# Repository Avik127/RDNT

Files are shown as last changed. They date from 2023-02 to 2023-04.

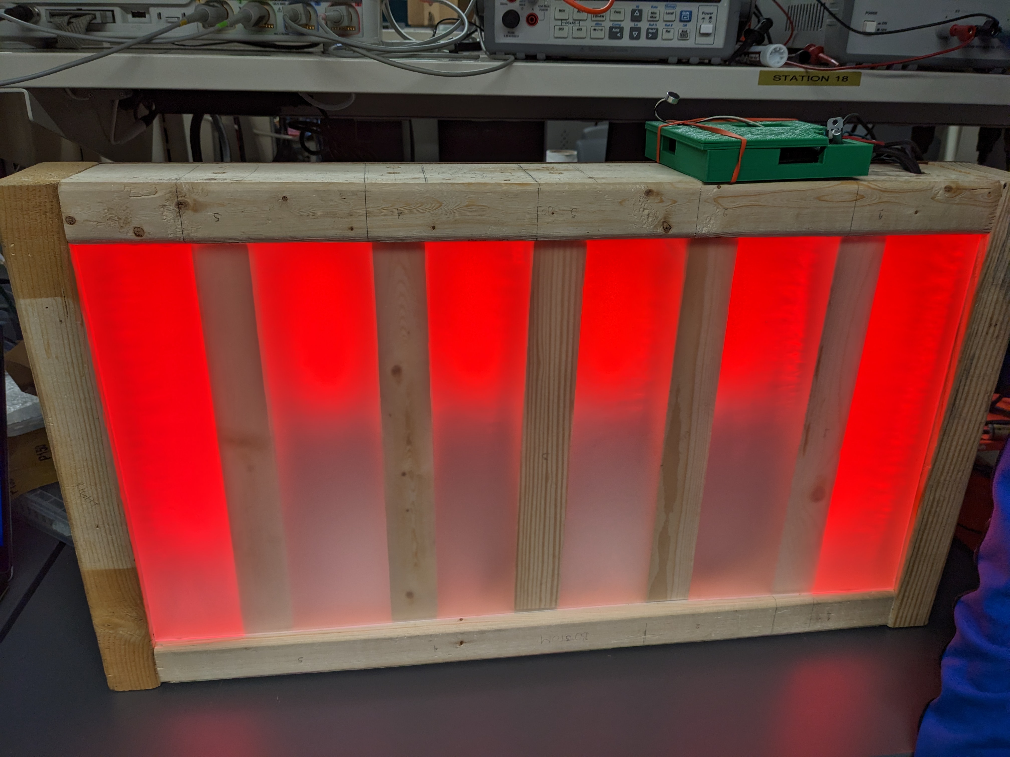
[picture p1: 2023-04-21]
website/Team/progress/progress2pics/final_construction_2.jpg

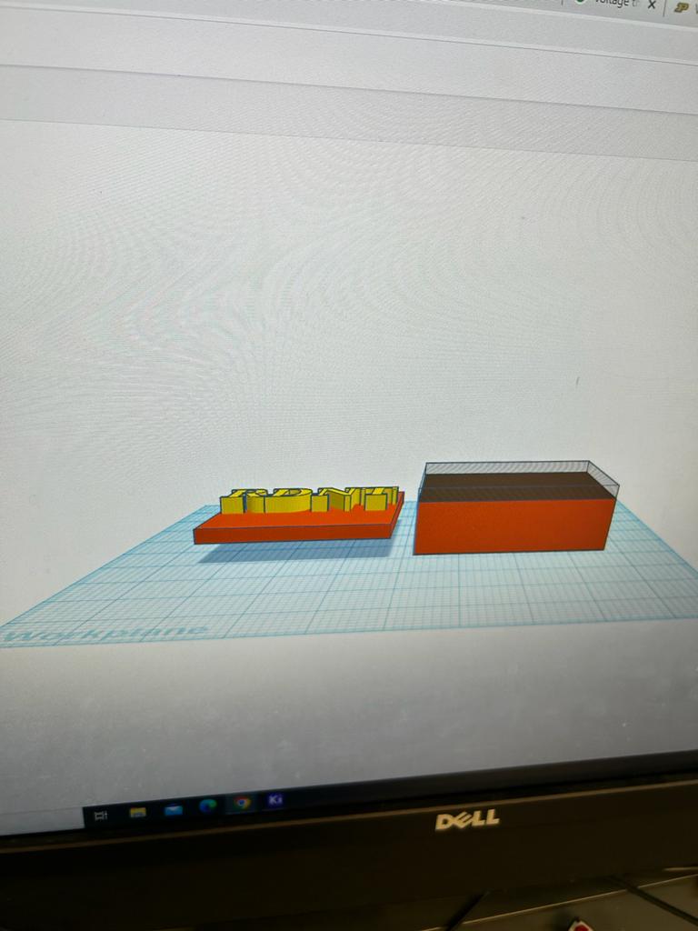
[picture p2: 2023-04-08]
website/Team/progress/resources4/design02.jpeg

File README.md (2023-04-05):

# RDNT

RDNT is a project that takes an input audio source and runs signal processing algorithms to drive wired LED strips to create a synchronized audio-visual experience. These audio sources are an onboard analog microphone, an AUX-in port, and a Bluetooth signal from our associated Android app. The user will be able to toggle through the 3 modes, with the microphone being the default, by pressing an external button. This mode toggling will be achieved through a multiplexxed circuit that selects the current mode.
The signal processing algorithms that will be used are the FFT algorithm and a 1-D Gaussian filter. The Gaussian filter reduces noise on the input sample and the FFT algorithm uses this noise reduced signal to isolate frequencies. The LED strips will be driven by a message sender that accepts the output of FFT to create patterns on the wired LED strips.
To create patterns we will send PWM signals to the data pin of the LED strips, these patterns and their associated color ranges can be selected by the user using the associated Android app. The microcontroller will read input samples and compute signal processing algorithms to drive the message sender. The LED strips will be powered by a wall adapter from 120V AC to 5V DC. A switching regulator circuit will drop the 5V DC to 3.3V DC for our microcontroller. For demonstration purposes, we will construct an acrylic display.

See our website for more information: https://engineering.purdue.edu/477grp18/

Current Stage: Soldering components onto our PCB, working on final software, and creating device packaging

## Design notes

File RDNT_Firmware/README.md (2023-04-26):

# RDNT_Firmware

## ESP32.zip

This is the final code shipped for the project.

## PCB Verification Files

These files are used for testing the project as we solder on components. They are described below:

### TestMCU_CaseLED.c
This program requires FastLED library and runs in the Arduino framework. It blinks the LEDs white and black.

### TestMCU_CaseLEDNoLibraries.c
This program requies no libraries and implements the same functions as above by manually controlling the PWM signals. This program uses Espressif-IDF framework and is closer to the final implementation.

### TestMCU_ModeButton.c
This program is used to test that the mode button has been implemented correctly. It is lacking state reflection on the case LED, that will be implemented in the next file.

## Prototyping Tools

These are main.c or main.cpp files that have were used in early prototyping. Many of these files are lacking dependencies but these are clear from reading the files. None of these files are fit for release and exist here solely for archival purposes. Use at your own caution.

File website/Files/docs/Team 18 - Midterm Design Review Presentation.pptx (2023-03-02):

## ECE477 MIDTERM DESIGN REVIEW: TEAM #18

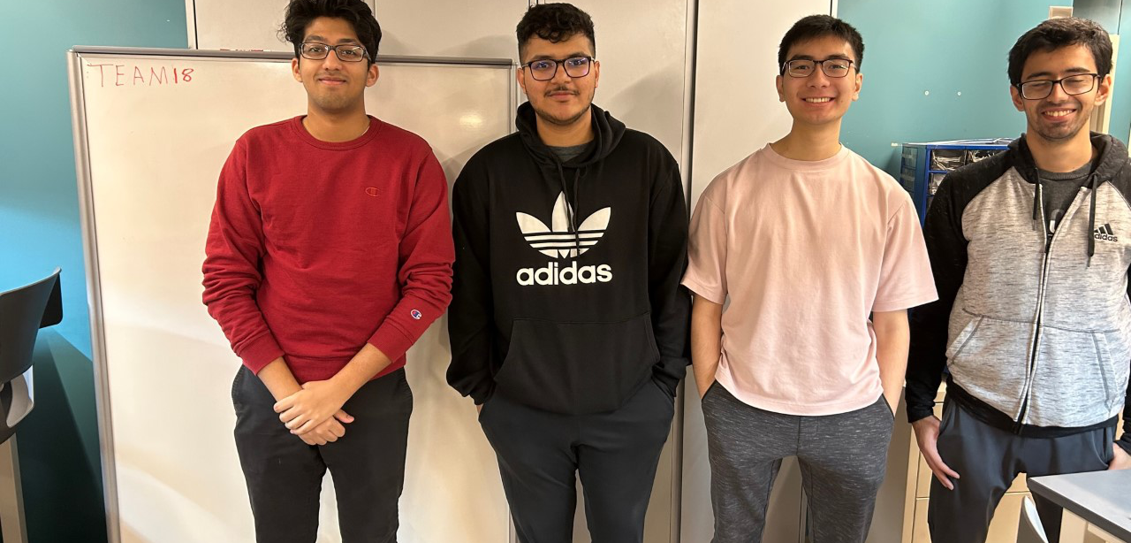
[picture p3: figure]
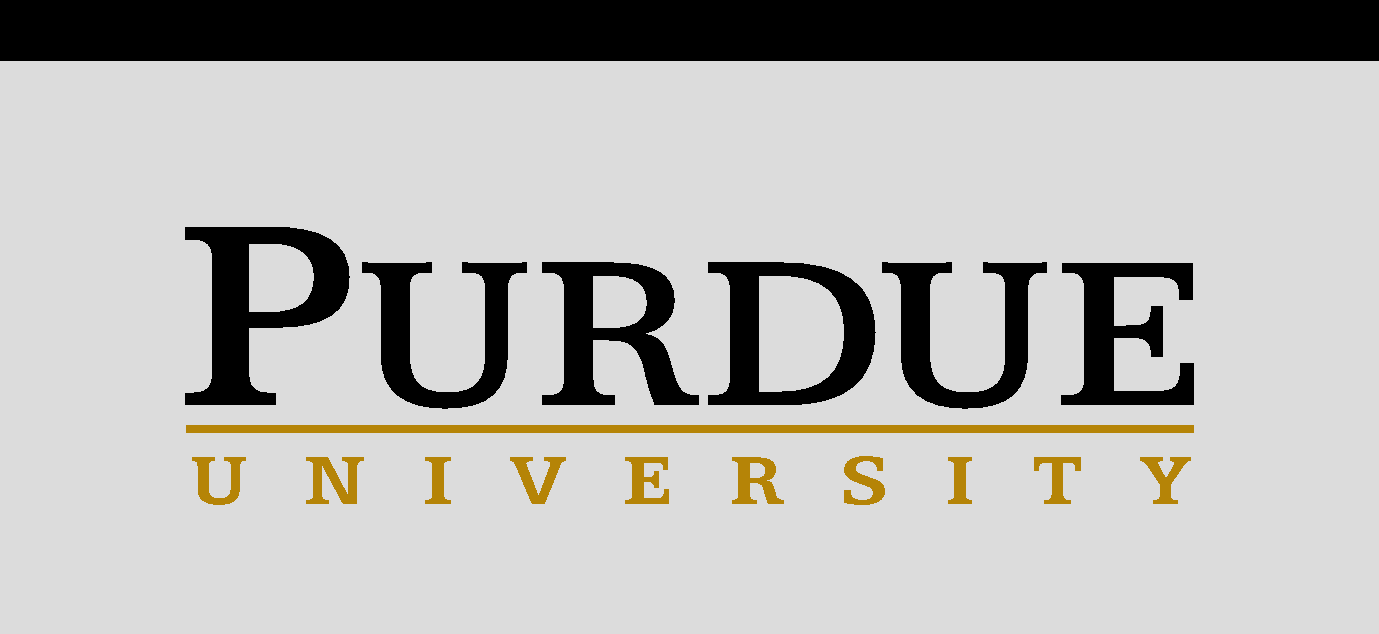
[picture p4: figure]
PU_sigtab.eps

## OUTLINE

- Project Overview
- PSSCs
- Block Diagram
- Major Components
- Prototyping Progress
- Electrical Schematic
- PCB Layout
- Software Development Status
- Packaging Design
- Project Timeline
- Questions

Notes: anu

## PROJECT OVERVIEW

Audio visualizer that lights up an LED display to correspond with input audio
- Real time analysis of input audio
- Easily configure patterns and colors through associated Android app
- Multiple audio input modes: Microphone, AUX, Bluetooth

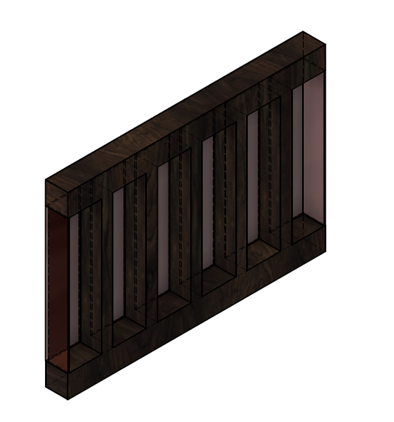
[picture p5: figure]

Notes: anu

## PSSCS

- PSSC #1 (Software): The ability to reduce noise on analog inputs through the use of a 1-D Gaussian Filtering algorithm.
- PSSC #2 (Software): The ability to control and configure multiple connected LED devices through a in-built bluetooth module that connects with Android app through UART.
- PSSC #3 (Hardware): The ability to amplify and filter analog input of the microphone using a sequence of operational amplifiers.
- PSSC #4 (Hardware): The ability for the user to toggle between input modes through multiplexed external controls. These modes will be Microphone (default), AUX-in, and Bluetooth audio.
- PSSC #5 (Hardware): The ability to drive multiple WS2812B LED strips with PWM signals and reactively display patterns in response to audio signals.
- Stretch Goal #1: The ability to isolate frequencies using the FFT algorithm.
- Stretch Goal #2: The ability to regulate power down from 5V DC to 3.3V DC with a switching regulator.

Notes: anu

## BLOCK DIAGRAM

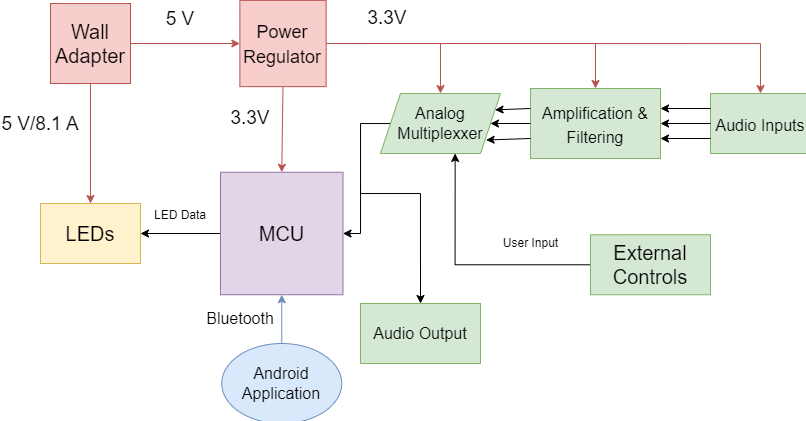
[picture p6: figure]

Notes: kahaan

## Component Selection: Synchronous Buck Converter

TPS56330

- 3.8V to 28V input voltage range
- 0.8V to 22V output voltage range
- 3-A continuous output current

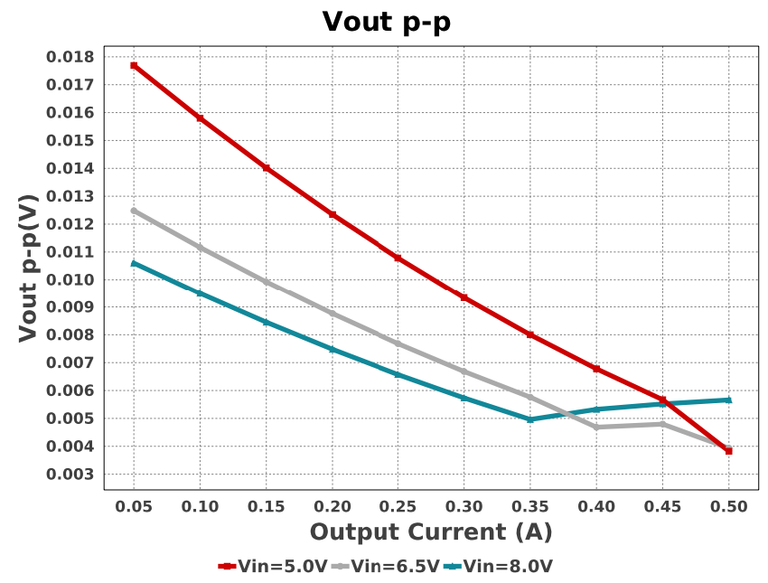
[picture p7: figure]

Voltage Input | 3.8V-28V
Voltage Output | 0.8V-22V
Current Output | 0A-3A

Recommended Characteristics

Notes: kahaan

## Component Selection: Microcontroller

ESP32-WROOM32

Selection Rationale:
- High Clock Speed: 80-240MHz
- Wi-Fi and Bluetooth capabilities
- Dual-Core CPU
- 520KB of RAM
- 4MB of Flash Memory
- 12-bit internal ADC peripheral
- Familiarity
- Cost effective

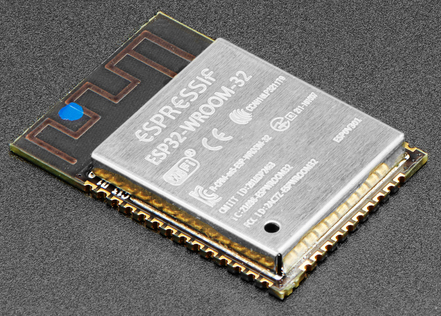
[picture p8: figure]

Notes: kahaan

## Component Selection: LEDs

WS2812B

Selection Rationale:
- 3-pin channels allow for individual addressability
  - Previous generation of LEDs (WS2811) only had separate channels for RGB
- Send data speed of 800 Kbps
- Scan frequency 400Hz

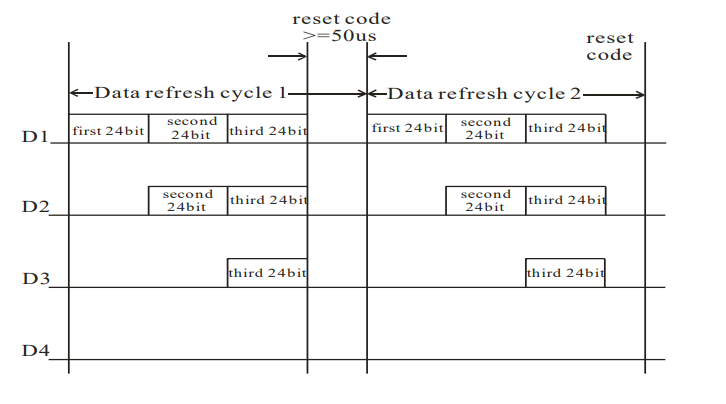
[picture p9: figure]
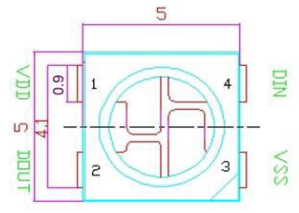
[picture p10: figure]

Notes: kahaan

## Prototyping Progress

Component | Status
Microphone Audio Filtering | 60%
Aux Input/Output | 80%
Power Circuit | 0%
Audio Multiplexer | 0%

The remaining progress in each of this component is primarily focused on software development:
- Audio filter through Gaussian Filtering algorithm
- AUX input output routing through Analog Multiplexer to AUX
- Audio input sampling, FFT, and visual pattern generation combined system

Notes: graeme

## Prototyping Progress

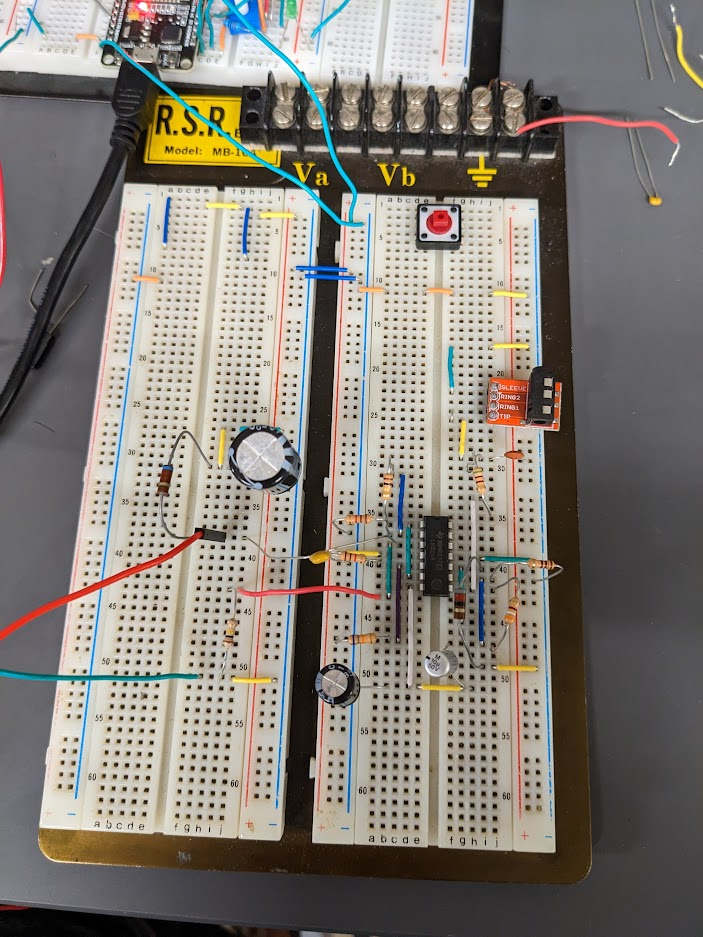
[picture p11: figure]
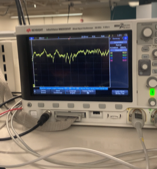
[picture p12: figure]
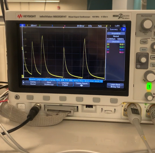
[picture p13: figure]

Microphone and AUX prototyping circuit, with oscilloscope readings

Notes: graeme

## ELECTRICAL SCHEMATIC

Full Schematic

## ELECTRICAL SCHEMATIC

Power

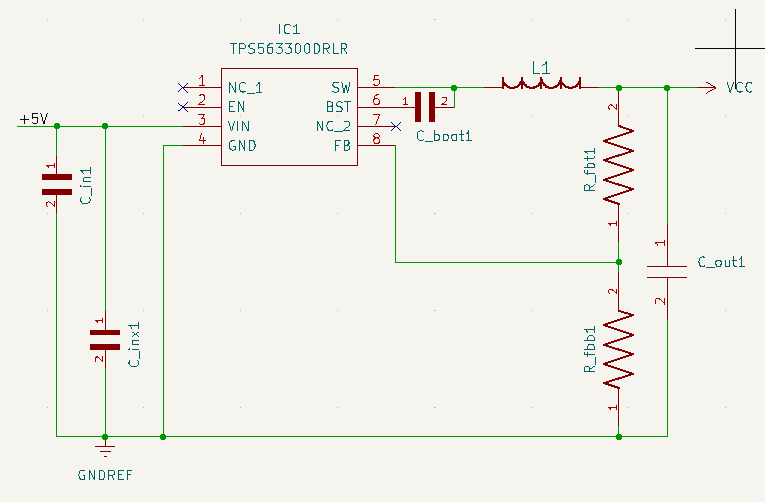
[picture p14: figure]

- Designed using the TI Power WEBENCH
- Input Voltage of 5V
- Supplies 3.3V @ 0.5A to the MCU

## ELECTRICAL SCHEMATIC

Mic Amplifier and Filtering

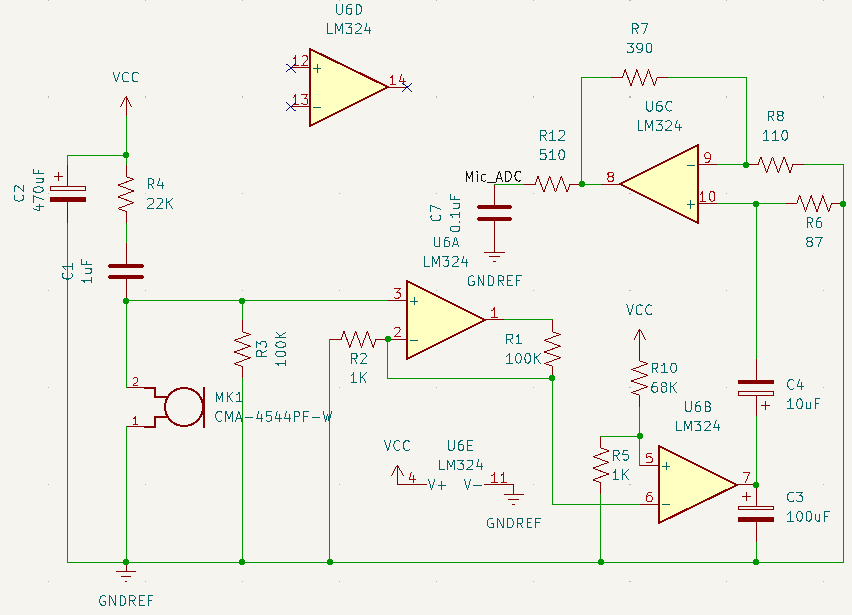
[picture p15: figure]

- Non-inverting op amp with a gain of 101x
  - Vout = Vin(1+(R1/R2))
- Low Pass Filter cutoff frequency @ ~3kHz
  - fc= 1/2πR12C7
- High Pass Filter cutoff frequency @ ~187Hz
  - fc= 1/2πR6C4

## ELECTRICAL SCHEMATIC

Analog Mux

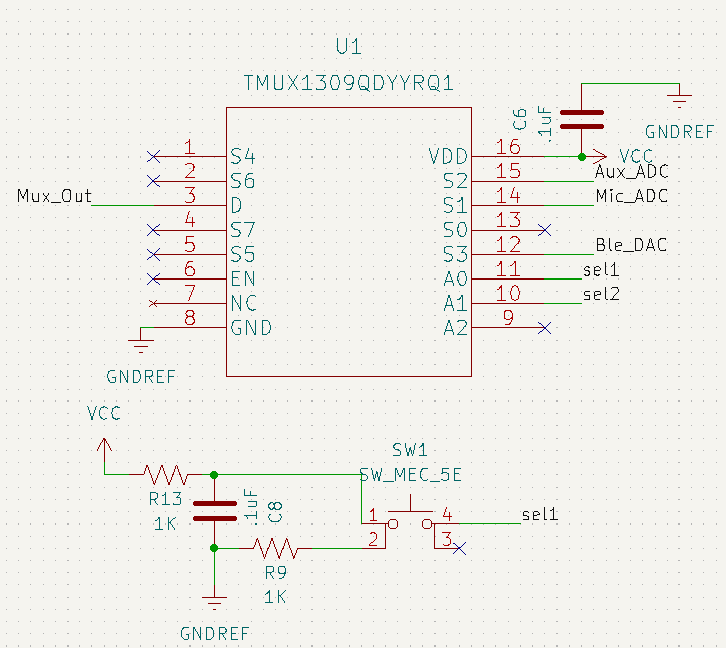
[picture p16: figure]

- Debouncing done on the mode-switching button
- Analog inputs are chosen through select lines controlled by MCU/push button

## ELECTRICAL SCHEMATIC

Aux Audio

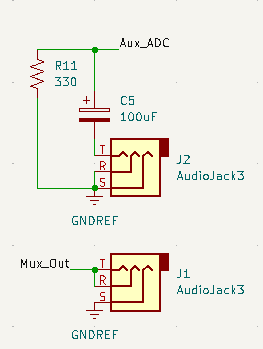
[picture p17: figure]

## ELECTRICAL SCHEMATIC

Microcontroller

## PCB LAYOUT

Full PCB

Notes: avik

## PCB LAYOUT

Power

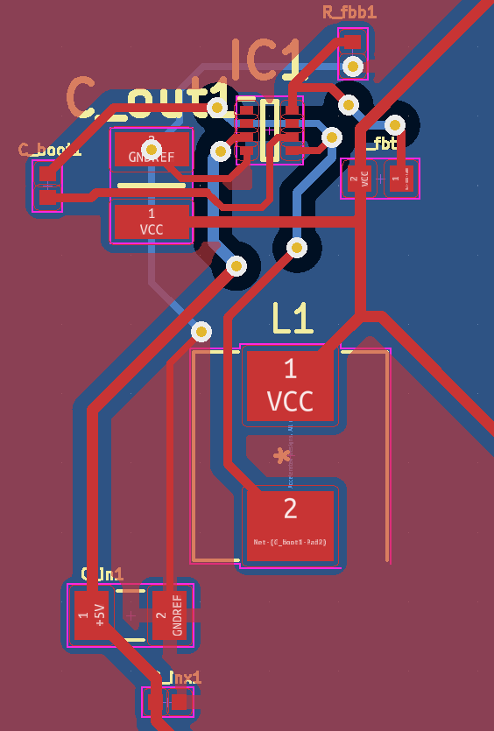
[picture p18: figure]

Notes: avik

## PCB LAYOUT

Microcontroller

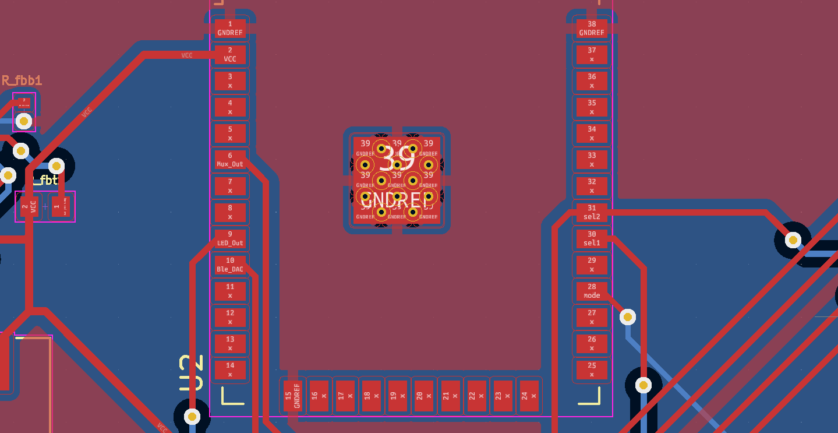
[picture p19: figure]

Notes: avik

## PCB LAYOUT

Aux Jacks

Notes: avik

## PCB LAYOUT

TMUX

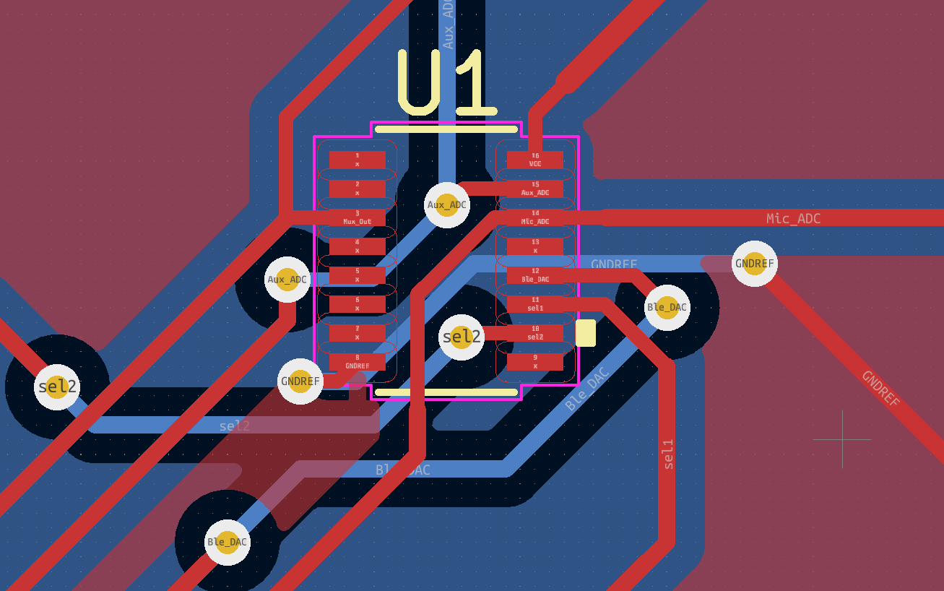
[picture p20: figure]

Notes: avik

## PCB LAYOUT

Mic

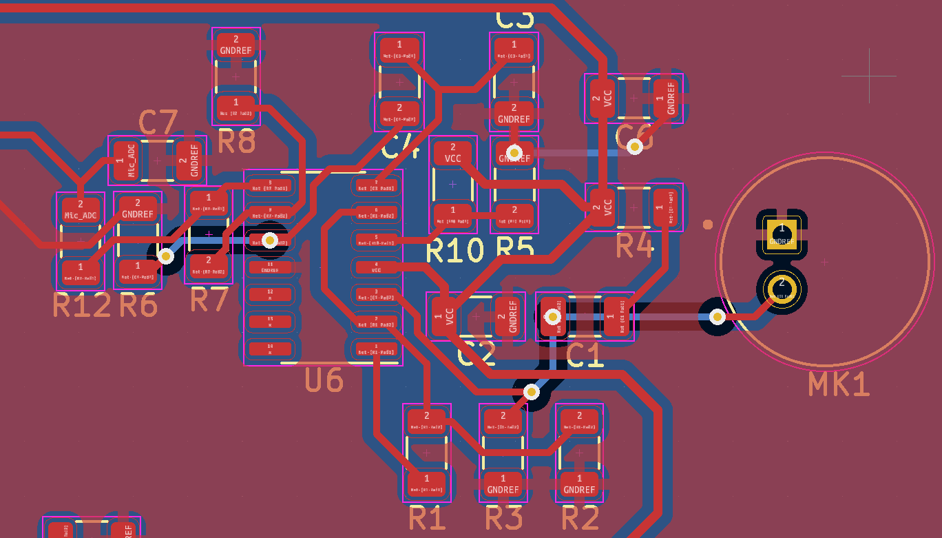
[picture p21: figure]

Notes: avik

## PCB LAYOUT

Debug Port and Mode Switch Button

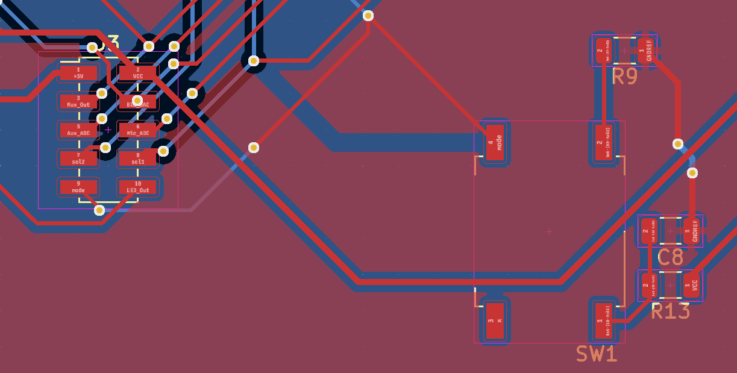
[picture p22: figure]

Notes: avik

## SOFTWARE DEVELOPMENT STATUS

App Development

- Connect/Disconnect
- Turn On/Turn off Leds
- 2 Core Features
  - Dancing
    - Light Color Control
    - Preset Menu
  - Brightness
    - Light Intensity Control
    - Preset Menu
- Ability to send 16 bit int to parse state.

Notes: kahaan

## SOFTWARE DEVELOPMENT STATUS

Firmware Development

Component | Status
Continuous ADC sampling | 100%
Continuous DAC output | 0%
Gaussian Smoothing | 100%
FFT Algorithm | 80%
LED control | 66%
Input Mode Switching | 0%
Communication with Android App | 10%

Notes: anu

## PACKAGING DESIGN

PCB Housing (Open)

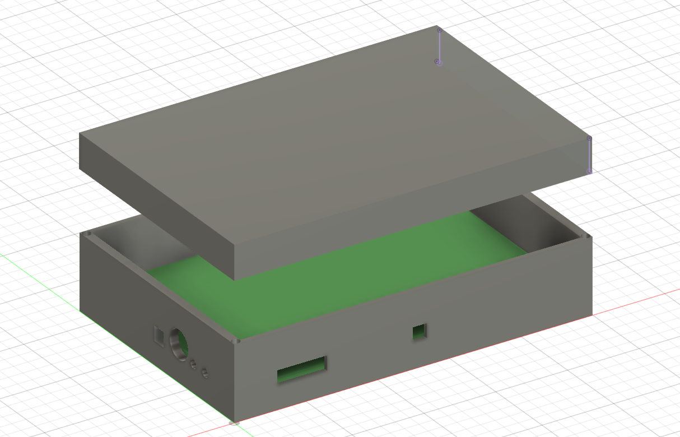
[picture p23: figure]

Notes: anu

## PACKAGING DESIGN

PCB Housing (Closed)

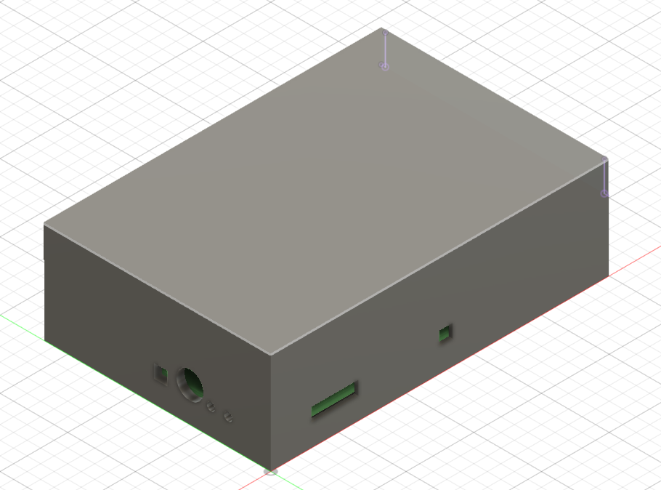
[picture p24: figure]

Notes: anu

## PACKAGING DESIGN

PCB Housing Dimensions

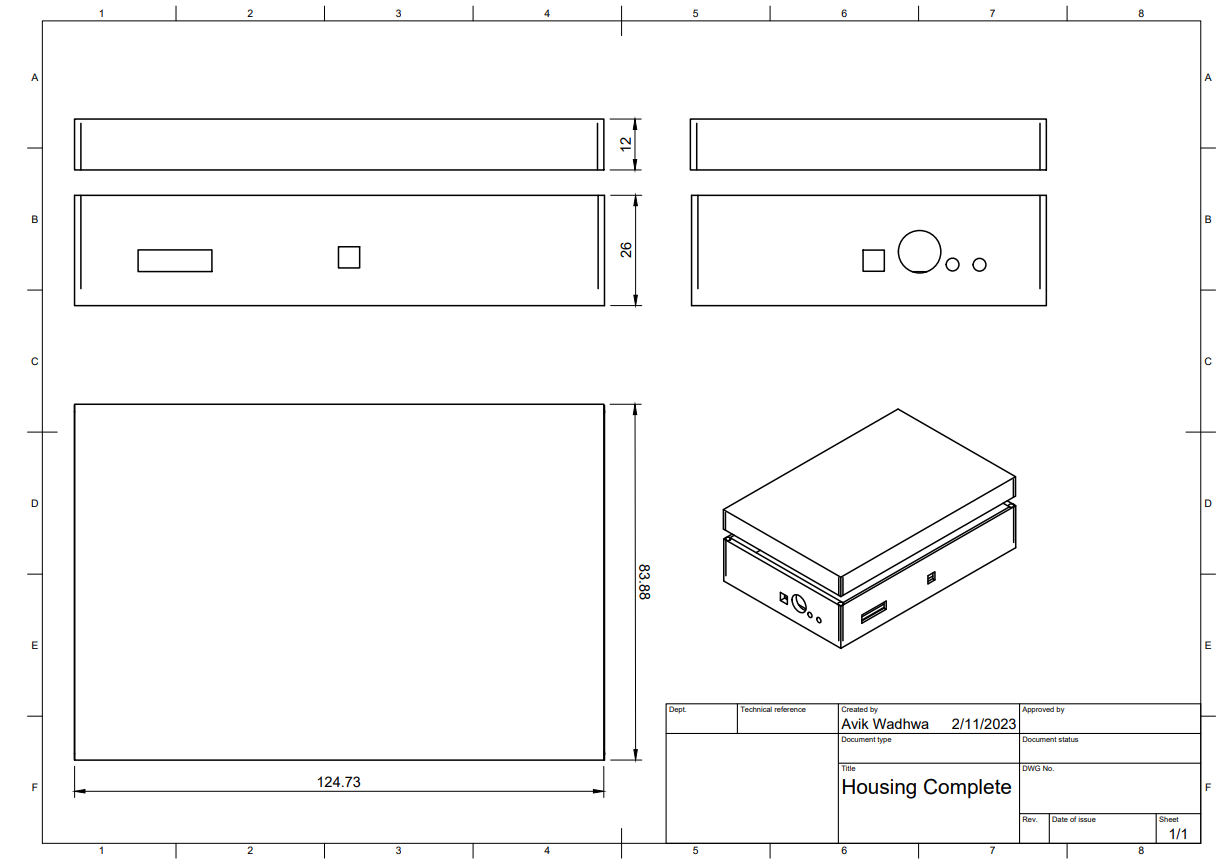
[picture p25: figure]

units: mm

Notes: anu

## PACKAGING DESIGN

LED Fixture Dimensions

units: mm

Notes: anu

## PROJECT TIMELINE

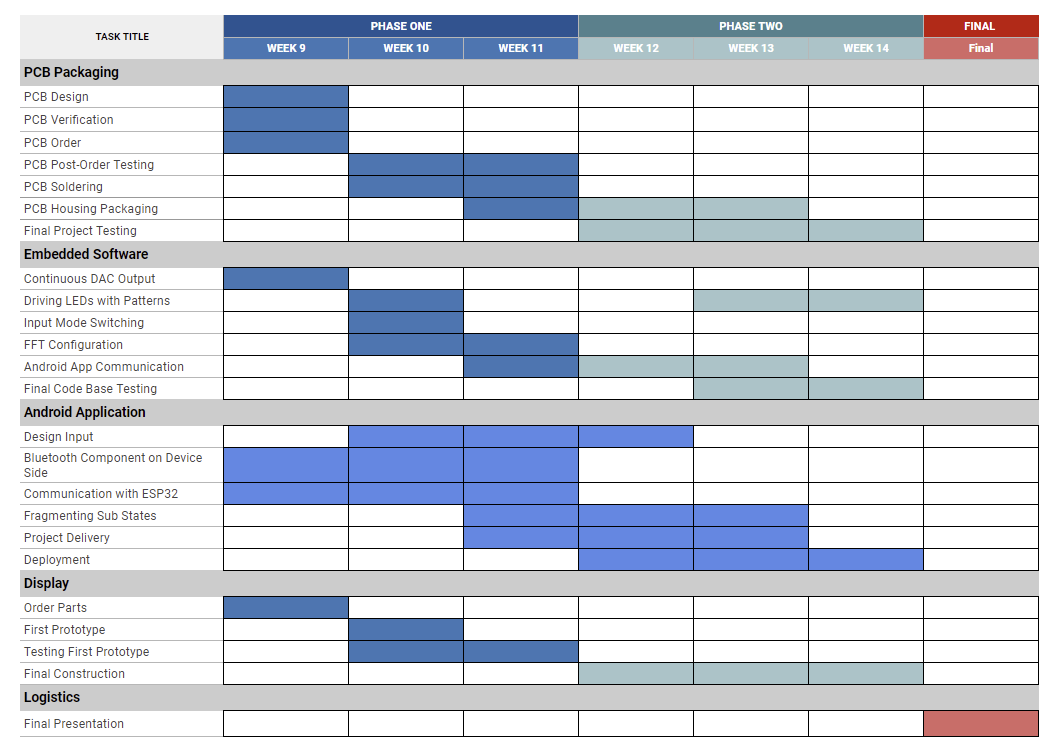
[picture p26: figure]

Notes: anu

## 3D PRINTING

Questions?

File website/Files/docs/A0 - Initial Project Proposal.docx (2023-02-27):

# Initial Project Proposal

# Year: 2023 Semester: Spring Project Name: RDNT

# Creation Date: November 21, 2022 Last Modified: February 23, 2023

# Team Members (#1 is Team Leader):

# Member 1: Anurag Numboori Email: anumboor@purdue.edu

# Member 2: Avik Wadhwa Email: wadhwa13@purdue.edu

# Member 3: Kahaan Patel Email: pate1410@purdue.edu

# Member 4: Graeme Usman Email: gusman@purdue.edu

# 1.0 Description of Problem:

Adding a visual element to audio playback creates a deeper connection in the audience. This allows for the creation of an experience, rather than just an occurrence. It is often difficult to create an audio-visual experience within economic constraints. Existing solutions are often expensive, non-customizable, and non-modular. Customers desire an inexpensive, customizable plug-and-play device that instantly connects with their smartphones for use with streaming services.

# 2.0 Proposed Solution:

The team proposes an alternative device to the current audio-visual enhancing devices that are currently being produced. Our device would create a solution that incorporates a system of LED lights and generates synchronous outputs that would elevate the visual impact in response to music.

Device 1

Device 2

Device 3

Controller

Mobile Device

=Transceiver

The functional evaluation of our prototype would be based on the following criteria:

- The ability of our LED devices to be controlled by a mobile device, verified through the demonstration of visual effects in response to inputs from the mobile device.
- The ability of our LED devices to respond to audio inputs, demonstrated by visual effects in response to music inputs from the mobile device.
- The ability of our device to provide a synchronized visual output with multiple LED lights.
- The ability of our device to capture and adapt to specific frequencies in musical inputs and generate a visual response based on the tempo of specific frequencies.
- The ability for an end user to install and establish a bluetooth connection with our device with minimal complexity.

# 3.0 ECE477 Course Requirements Satisfaction

# 3.1 Expected Microcontroller Responsibilities

Our device would use the microcontroller for the following functions: on-board signal processing; i.e. frequency filtering/isolation, frequency assignment to LED patterns and colors, and establishing an I/O connection with a mobile device through an external bluetooth device.

# 3.2 Expected Printed Circuit Responsibilities

We will develop a PCB with following features:

1. Power Regulator
2. External Bluetooth Device
3. LED Drivers
4. Microcontroller

Other functionality may be included as the ECE477 design semester progresses.

# 4.0 Market Analysis:

In 2021, over 20 million students were enrolled in higher education [1]. A popular past-time of this demographic is house parties, where loud music is a staple in a party environment. Our device would appeal to this demographic, transforming a mostly-audio experience into an audio-visual experience. Spotify alone has 195 million subscribers worldwide [2]. Users of streaming apps such as Spotify would be able to instantly use our device to create audio-visual experiences. This device could also appeal to establishments like restaurants and bars that wish to enhance the experience of their customers. Similarly, stadiums could use this device to help create excitement for events.

# 5.0 Competitive Analysis:

# 5.1 Preliminary Patent Analysis:

Prior art proposing the idea of music reactivity or visualization through displays exists previously, and the relevant patents to their designs are described below. Our project is expected to function similarly to them, and so their existence helps protect against any possible patent infringement.

# 5.1.1 - China Patent Application CN2261133Y:

Patent Title: “Music-light electronic changer”

Patent Holder: Expired
Patent Filing Date: 3 December, 1994

This patent [3], describes “A signal pickup and decomposition circuit is used for analyzing a music signal into a sound intensity, sound height and sound quality signal which can represent the details of music.”, which is very similar to what our proposed system is trying to accomplish. The patent goes into detail of how to create an audio-visual experience, combining music theory and colorimetry theory. This is done by having the characteristics of the music playing: loudness, pitch, and tone) be the parameters used to control the colored lights’ elements: brightness, tone, and color saturation.

Our design hopes to give much more customizability of the color response of the display, while still creating a vibrant audio-visual experience through realtime music reactivity of the lights.

# 5.1.2 - US Patent Application US9561449B2:

# Patent Title: LED lighting device and wireless speaker

Patent Holder: Zhejiang Shenghui Lighting Co Ltd

Patent Filing Date: 3 September, 2014

This patent [4], is most similar to our proposed design, comprised of “...an LED light source module configured to emit light…”, as well as “...a DLNA wireless communication module configured to receive and process audio signals and commands transmitted from a smart terminal… [to control] the LED lighting device…”, and “and a speaker unit configured to play audio signals received”, as well as all the relevant power sources needed to drive these parts. The mentioned “smart terminal” is later specified as being “...a smart phone, a smart television, a tablet, a desktop, etc…”.

# For our design, much of the audio signal processing will be done by microcontroller, while our “smart terminal”, a phone app in this case, would be a device controlling color and other parameters. as it aims to function very similarly to our proposed project.

# 5.1.3 - US Patent Application US8461443B2:

Patent Name: Control of light in response to an audio signal

# Patent Holder: TP Vision Holding BV

Patent Filing Date: 25 October, 2007

This patent [5], has a similar functionality to our project design, but goes into much more detail of the functionality of the light control parameters designed to “...allow musical content and lighting to be freely combined, especially for a very wide range of audio signals…” and “...to provide a method and apparatus that can automatically control lighting such as ambient lighting so that changes in lighting perceptually correspond to changes in audio signals…”. This “method” referenced throughout is described as being able to extract relevant “semantic content of the audio signal” and translate that into “[l]ighting control parameters”.

# A major advantage that is highlighted in this patent is “[t]he ability to provide time aligned lighting effects…”. Synchronizing our LEDs’ visual response with our audio was a major discussion point, and hopefully this patent will be able to point us in the right direction.

# 5.2 Commercial Product Analysis:

Comprehensive web searches through Google and online marketplaces, such as Amazon, were done to find commercial products that perform similarly to our proposed project design. The products described below are ones that we felt were functionally similar to our project, and/or provided us with inspiration for said project.

# 5.2.1 Philips Hue

# Philips’ line of Hue Lights [6] were the main inspiration for this project, being the most widely-known product line that accomplishes the audio-visual mix that we are proposing.

Philips offers a wide variety of lights, from smart bulbs to LED strips, allowing for customers to find the product that fits their specific needs. The ecosystem of these products allows for modularity of these lights, but at the cost of full customizability for the user. The user can use bluetooth to connect multiple lights, but this comes with the cost of limited functionality. It highly recommended to use the proprietary Bridge device for full functionality, which is another item you have to add to your cart.

Our product hopes to be as modular and self-integrated as the Hue lights are; if we want to add more than one or two lighting fixtures to our design, it should be seamless and hassle-free to do so.

# 5.2.2 Douk Audio LED Audio Level Display

This product [7] offers a much more basic package and functionality than the Philips Hue Lights, but with that comes cost effectiveness and an all-in-one package. The audio visualization is done through environmental sound detection through a microphone on the back of the device, and the different Audio Displays come with varying levels of definition, from a 16-bit display, all the way up to a 128-bit display. This leads to the product needing audio to be played through speakers (not included), being subject to ambient noises, and means that there is no separation between different frequency bands.

Our project hopes to be able to be an all-inclusive design, while also having a much more fleshed out visual display that reacts to the audio being played.

# 5.2.3 ViVi - Visual Vibes

This product [8] is most similar in direction and purpose to our design, with the multiple modular offerings like the Philips Hue. The most expensive of the three in terms of per piece of equipment, and utilizing the proprietary controller idea, this product is similar in function to ours, but hopefully not cost.

This product is not “commercial” in the traditional sense, as it was crowdfunded through Indiegogo, and its availability is questionable, but from a design perspective, it is claiming to do everything that we are setting out to do as well: bluetooth audio connectivity, precision beat recognition and frequency association, and a plug-and-play final product.

# 5.3 Open Source Project Analysis:

The idea of combining music with reactive visualization through lights or other forms of displays is an ever-expanding idea throughout tech, with LEDs becoming cheaply available and processing power increasing yearly, making concurrent audio signal processing much more feasible. These factors allow hobbyists to make projects akin to ours, and provide those similarly interested with the resources they used.

# 5.3.1 Audio Reactive LED Strip

This project [9] is licensed under MIT license. The only requirement is the original license and copyright notice must be preserved. This project outlines two forms, the first uses a computer application to run all signal processing and LED visualization calculations. It then sends this information through WiFi to the microcontroller which only sends the visualization routines to the LEDs. Our project would run the calculations on the microcontroller itself. This would allow us to generalize our audio input to any bluetooth stream. We can consider using the WiFi connection for LEDs to app synchronization for our project. The project’s second form is more similar to our intended project, it uses a USB audio-in connected to a microcontroller to drive the LEDs. Both forms result in a very interesting 1-D visualization which we can consider implementing a similar form in our project.

# 5.3.2 LedFx

This project [10] is licensed under GPL-3.0. Requirements for use include preservation of original license and copyright notice, changes must be stated, the source must be disclosed, and GPL-3.0 license must be used. This project is similar to our intended project, but requires a computer app, LedFx. Our device will instead use bluetooth streams and therefore can accept input from any device with bluetooth capabilities including computers and phones. Their project also has an API used for driving LEDs and changing configurations quickly. If time allows, this is a good addition to our project to make it easier for users to customize from the phone app.

# 5.3.3 Retro LED Strip Audio Visualizer

This project [11] does not have a license. It is very stylized and uses acrylic/trash bags over the LEDs for a diffusion effect. Where our project will have a bluetooth module and a power regulator on our PCB, this project uses a prebuilt logitech bluetooth to AUX device, a prebuilt power regulator, and a breadboard. All of these differences make the project’s electronics look less professional than our intended project. Their project uses a fast fourier transform on the original signal where we will plan to use low pass filters to isolate common percussion notes.

# 6.0 Sources Cited:

[1] “College Enrollment & Student Demographic Statistics”. Education Data Initiative. https://educationdata.org/college-enrollment-statistics (accessed Dec. 17, 2022)

[2] “About Spotify”. Spotify For The Record. https://newsroom.spotify.com/company-info (accessed Dec. 17, 2022)

[3] Music-light electronic changer by 张朝辉, 郭九苓. (1994, Dec. 3). CN2261133Y. Available: https://patents.google.com/patent/CN2261133Y/en

[4] LED lighting device and wireless speaker by Xia Wang, Jinxiang Shen. (2014, Sept. 3). US9561449B2. Available: https://patents.google.com/patent/US9561449B2/en

[5] Control of light in response to an audio signal by Martin Franciscus McKinney, Janto Skowronek, Dragan Sekulovski, Bram Kater. (2007, Oct. 25). US8461443B2. Available: https://patents.google.com/patent/US8461443B2/en

[6] “Sync with music”. Philips-Hue. https://www.philips-hue.com/en-us/explore-hue/propositions/entertainment/sync-with-music (accessed Dec. 17, 2022).

[7] “Douk Audio Music Levels Light RGB LED MIC Sound Level Meter Audio Spectrum Display Analyzer”. Douk Audio & Nobsound. https://doukaudio.com/collections/led-display/products/douk-audio-music-levels-light-rgb-led-mic-sound-level-meter-audio-spectrum-display-analyzer (accessed Dec. 17, 2022).

[8] “Bring the Concert Experience Home”. Visual Vibes LED Shop - Sound Reactive Lighting Controllers. https://visualvibes.io/ (accessed Dec. 17, 2022).

[9] Lawson, Scott. “scottlawsonbc/audio-reactive-led-strip”. GitHub. https://github.com/scottlawsonbc/audio-reactive-led-strip (accessed Dec. 17, 2022).

[10] “LedFx”. LedFx - LED Music Visualizer. https://www.ledfx.app/ (accessed Dec.17, 2022).

[11] “Retro LED Strip Audio Visualizer”. Yours for the making - Instructables. https://www.instructables.com/Retro-LED-Strip-Audio-Visualizer/ (accessed Dec 17, 2022).

# Appendix 1: Concept Sketch

Device 1

Device 2

Device 3

Controller

Mobile Device

=Transceiver

https://engineering.purdue.edu/ece477 Page 1 of 2

ECE 477: Digital Systems Senior Design Last Modified: 02-27-2023

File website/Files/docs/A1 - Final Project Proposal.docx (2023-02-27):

# Final Project Proposal

# Year: 2023 Semester: Spring Team: 18 Project: RDNT

# Creation Date: 11 January 2023 Last Modified: 27 February 2023

# Team Members (#1 is Team Leader):

# Member 1: Anurag Numboori Email: anumboor@purdue.edu

# Member 2: Graeme Usman Email: gusman@purdue.edu

# Member 3: Avik Wadhwa Email: wadhwa13@purdue.edu

# Member 4: Kahaan Patel Email: pate1410@purdue.edu

# 1.0 Project Description:

RDNT is a project that takes an input audio source and runs signal processing algorithms to drive wired LED strips to create a synchronized audio-visual experience. These audio sources are an onboard analog microphone, an AUX-in port, and a Bluetooth signal from our associated Android app. The user will be able to toggle through the 3 modes, with the microphone being the default, by pressing an external button. This mode toggling will be achieved through a multiplexxed circuit that selects the current mode.

The signal processing algorithms that will be used are the FFT algorithm and a 1-D Gaussian filter. The Gaussian filter reduces noise on the input sample and the FFT algorithm uses this noise reduced signal to isolate frequencies. The LED strips will be driven by a message sender that accepts the output of FFT to create patterns on the wired LED strips.

To create patterns we will send PWM signals to the data pin of the LED strips, these patterns and their associated color ranges can be selected by the user using the associated Android app. The microcontroller will read input samples and compute signal processing algorithms to drive the message sender. The LED strips will be powered by a wall adapter from 120V AC to 5V DC. A switching regulator circuit will drop the 5V DC to 3.3V DC for our microcontroller. For demonstration purposes, we will construct an acrylic display.

# 2.0 Roles and Responsibilities:

# 1. Anurag Numboori Team leader – Maintains communication among team members, ensures team is progressing and assists fellow team members in addressing significant issues

Anurag was able to develop his leadership abilities as Design Lead for his EPICS WRM team as a freshman. He used this experience as Design Lead of a 6-person team to learn powerful skills in compromising and keeping a team focused. He is also interested in software, which he draws from his experience in an internship and many high-level software courses. His interests include Web Development, Computer Security, and Game Design.

# 2. Graeme Usman Systems engineer – Responsible for high level functional overview of the system, including the theory of operation, block diagram, and component selection. Ensures components and systems on project work together coherently

Graeme has had experience working in software and hardware, as well as collaborating with engineers of similar backgrounds. He will be the systems engineer for the team, making sure that all components are integrated properly with each other, while maintaining a high-level view of the overall objective for RDNT.

# 3. Avik Wadhwa Hardware engineer – Responsible for design of printed circuit board electrical schematics and layouts, often in charge of circuit board construction and packaging assembly

Avik is significantly involved with learning more about embedded systems. Throughout his internship at Milwaukee Tool, Avik strived to develop an embedded prototype within project guidelines that are very similar to the scope of this class. He also has experience with developing quick CAD models for prototyping. Avik’s background and passion toward this project makes him a good fit for designing the PCB and developing the packaging assembly.

# 4. Kahaan Patel Software Engineer – Responsible for design and implementation of source code. Undertakes functional prototyping efforts early in the semester to mitigate risk in the later stages of the design process

Kahaan is a pioneering software engineer. He has strong experience in networks and also has experience with building web applications. Kahaan is a fast-learner who believes in rapid prototyping and loves to build software for networked systems, which makes him a great fit for being the Software Engineer for this project.

# 2.1 Homework Assignment Responsibilities

Design Component Homework | | Professional Component Homework
A3-Software Overview | AN | A9-Legal Analysis | AW
A4-Electrical Overview | AW | A10-Reliability and Safety Analysis | KP
A6-Mechanical Overview | GU | A11-Ethical/Environmental Analysis | AN
A8-Software Formalization | KP | A12-User Manual | GU

# 3.0 Estimated Budget

Category | Description | Total Estimated Cost ($)
PCB | The overall cost of printing the schematic | 50
Electronics | Includes: Microcontroller Power Distribution Electronics Bluetooth Modules LED Drivers | 65
Speakers | Audio Speakers to play music the lights are syncing | 100
LED Array | LEDs we will be using that will visually sync with the music | 60
Acrylic Diffuser Prototype LED addressable strip | Housing for the LEDs to improve visual appearance | 40
Microphone | For prototype testing of audio I/O | 30
Packaging | Will buy project box or materials to 3D print a box and multiple iterations. | 30
Web Domain | For maintaining archive of project | 50
Total | | 425

# 4.0 Project Specific Success Criteria

PSSC #1 (Software): The ability to reduce noise on analog inputs through the use of a 1-D Gaussian Filtering algorithm.

PSSC #2 (Software): The ability to control and configure multiple connected LED devices through an in-built Bluetooth module that connects with an Android app through UART.

PSSC #3 (Hardware): The ability to amplify and filter analog input of the microphone using a sequence of operational amplifiers.

PSSC #4 (Hardware): The ability for the user to toggle between input modes by using multiplexxed external controls. These modes will be Microphone (default), AUX-in, and Bluetooth audio.

PSSC #5 (Hardware): The ability to drive multiple WS2812B LED strips with PWM signals and reactively display patterns in response to audio signals.

Stretch Goal #1: The ability to isolate frequencies using the FFT algorithm.

Stretch Goal #2: The ability to regulate power down from 5V DC to 3.3V DC with a switching regulator.

# 5.0 Sources Cited:

# No external works were used to write this report.

https://engineering.purdue.edu/ece477 Page 3 of 3

ECE 477: Digital Systems Senior Design Last Modified: 02-27-2023

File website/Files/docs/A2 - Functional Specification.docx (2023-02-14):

# Functional Specification

# Year: 2023 Semester: Spring Team: 18 Project: RDNT

# Creation Date: 11 January 2023 Last Modified: 21 January 2023

# Team Members (#1 is Team Leader):

# Member 1: Anurag Numboori Email: anumboor@purdue.edu

# Member 2: Graeme Usman Email: gusman@purdue.edu

# Member 3: Avik Wadhwa Email: wadhwa13@purdue.edu

# Member 4: Kahaan Patel Email: pate1410@purdue.edu

# Assignment Evaluation:

Item | Score (0-5) | Weight | Points | Notes

Assignment-Specific Items
Functional Description | | x3
Theory of Operation | | x3
Expected Usage Case | | x3
Design Constraints | | x3

Writing-Specific Items
Spelling and Grammar | | x2
Formatting and Citations | | x1
Figures and Graphs | | x2
Technical Writing Style | | x3
Total Score

# 5: Excellent 4: Good 3: Acceptable 2: Poor 1: Very Poor 0: Not attempted

# General Comments:

# 1.0 Functional Description

Our device will be able to interface with different addressable LEDs. We will build a diffused acrylic LED display but our device itself will be able to connect to any compatible LED device. Our device will have 3 modes. Mode 1 will accept audio input from a bluetooth device. Mode 2 will accept audio input through 3.5mm AUX-in from a compatible device. Mode 3 will use the onboard microphone to pick up audio. No matter the mode used, our device will display a lightshow on connected addressable LED strips. The lightshow will associate colors to frequencies and be modular for use with a customizable amount of LEDs. Our device will also feature a 3.5mm AUX-out for connection to external speakers. This allows the user to still be able to listen to the music when in Mode 1 and Mode 2. We will release an associated app that can be used to pick color ranges and initialize connections to LEDs.

# 2.0 Theory of Operation

Fast Fourier Transform is an algorithm that can be used to isolate frequencies. The algorithm uses Discrete Fourier Transform to find the frequencies that make up a given audio input wave. The frequencies that we want to isolate will correspond to common percussion instruments. This algorithm is O(Nlogn) instead of O(N^2) which will make it faster to compute on our microcontroller by reducing computations for known values.

# 3.0 Expected Usage Case

The expected usage case is inside of a room in the customer’s home. The device itself will be portable but the diffused acrylic LED display will be difficult to transport. However, our device will be modular so it can be transported independently of the original LED display and connected to another compatible LED display. Only one person will be able to connect to the device and play their own music at a time, but the output of the music will be visible and audible to anyone in the room. We expect our users to be college aged if they use the device in their homes. Another possible usage case is a restaurant or bar where the user will be the store’s manager using the device to create a lightshow for their guests.

# 4.0 Design Constraints

Needs to be usable with compatible LEDs. This means our current driver will need to draw a variable amount of current based on the amount of LEDs connected.

We must be able to synchronize LED’s with an audio stream processed by the microcontroller.

# 4.1 Computational Constraints

Computational constraints for our project consist of receiving an input of audio stream, through means which can be switched between an AUX input, Bluetooth audio, or a microphone. Computing Fast Fourier Transforms will require the most headroom, since it is the most calculation heavy. We will then use the isolated frequencies calculated by the Fourier transforms to drive the LEDs, and these commands will also require computation done by the microcontroller.

# 4.2 Electronics Constraints

We expect to need a separate ADC. This separate module will allow us to read greater differences in audio input voltages. Therefore, we will be able to parse greater detail in our audio inputs. Our project will include a diffused acrylic LED display that will be driven by a current driver circuit. We will use a bluetooth module on our microcontroller. We will also feature external controls that will be used to switch the mode and turn our device on and off. There will also be output to 3.5mm AUX-out so that the user can attach their own speakers.

# 4.3 Thermal/Power Constraints

The biggest concern will be driving the LEDs, as well as any heat output produced by them. Depending on how we design the housing for the LED’s, they could also prove to be a large source of heat. We will try to keep our device room temperature but the LEDs will probably heat up slightly when powered on.

Other sources of heat could be attributed to our power supply wall plug.

# 4.4 Mechanical Constraints

Our main device will be contained in a small box designed to fit to the size of our PCB, along with any peripheral I/O. This will be the main “device”, while the LED’s fixtures will be of variable amounts, with each fixture being about 1.5 ft tall, and around 3-4 inches length and width-wise. We are still deliberating on the idea of built-in speakers versus separate speakers to play audio, which could increase the footprint of our device as a whole.

# 4.5 Economic Constraints

The biggest cost will be to create the LED display, as we plan to buy hundreds of individual LEDs. Our project will be around 100 dollars for the device and around 200 dollars for the LED display.

# 4.6 Other Constraints

# 5.0 Sources Cited:


https://engineering.purdue.edu/ece477 Page of

ECE 477: Digital Systems Senior Design Last Modified: 1-21-2023

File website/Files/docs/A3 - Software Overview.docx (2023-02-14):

# Software Overview

# Year: 2023 Semester: Spring Team: 18 Project: RDNT

# Creation Date: 23 January 2023 Last Modified: 28 January 2023

# Author: Anurag Numboori Email: anumboor@purdue.edu

# Assignment Evaluation:

Item | Score (0-5) | Weight | Points | Notes

Assignment-Specific Items
Software Overview | | x2
Description of Algorithms | | x2
Description of Data Structures | | x2
Program Flowcharts | | x3
State Machine Diagrams | | x3

Writing-Specific Items
Spelling and Grammar | | x2
Formatting and Citations | | x1
Figures and Graphs | | x2
Technical Writing Style | | x3
Total Score

# 5: Excellent 4: Good 3: Acceptable 2: Poor 1: Very Poor 0: Not attempted

# General Comments:

# Relevant overall comments about the paper will be included here

# 1.0 Software Overview

Our device will allow the user to switch the device’s power ON and OFF. In external buttons/switches, the user will be able to change the mode of operation. There will be 3 modes: Microphone (default), aux-in, and bluetooth. In the first mode, an onboard microphone will capture analog input. In the second mode, analog input will be accepted through an aux socket (TRRS jack). In the third mode, digital input will be accepted through the ESP32's bluetooth module or an external Bluetooth input device. We are unsure currently if the ESP32 is fit to handle high quality digital inputs. Analog input to the device will be read by the ADC and sent to the FFT operations that we will implement. These FFT operations will isolate the driving percussion frequencies. Now that the frequency is isolated, we can send the frequency to our message sender. The message sender will use the default setup to send a color and pin number message to our LED strips.

We will also build a mobile application that the user will use to set the number of total LEDs. Our message sender will pick a color that mostly closely matches a frequency mapping for a given amount of LED output pins. This frequency to color mapping is dependent on the total amount of LEDs. Therefore, our message sender will be able to pick more appropriate colors/pin numbers for customization if more LEDs are connected.

# 2.0 Description of Algorithms

Fast Fourier Transform [1] is an algorithm that can be used to isolate frequencies. The algorithm uses Discrete Fourier Transform recursively to find the frequencies that make up a given audio input wave. The frequencies that we want to isolate will correspond to common percussion instruments. This algorithm is O(Nlogn) instead of O(N^2) which will make it faster to compute on our microcontroller by reducing computations for known values.

# 3.0 Description of Data Structures

The most important data structures are arrays used to store a single waveform and the output of our FFT. Our single waveform array is used as an input to FFT. We expect to have this array overwritten periodically so that the LEDs are always synced to a song as it changes. Our output array from FFT will clarify where the peaks in frequency are located. Each index in this array represents a “bin” of frequencies. The size of this array will decide the accuracy of our output colors. This array’s most useful index will be sent to the message sender.

Libraries control the driving of LEDs from our message sender. The libraries send variable period duty cycles to change the colors for a given LED on the strip. To change a given LED on the strip, it requires a 24-bit signal which is made of 0s and 1s, which are represented by a single period of the duty cycle.

# 4.0 Sources Cited:

# 1. https://jakevdp.github.io/blog/2013/08/28/understanding-the-fft/

# Appendix 1: Program Flowcharts


# Appendix 2: State Machine Diagrams


https://engineering.purdue.edu/ece477 Page of

ECE 477: Digital Systems Senior Design Last Modified: 01-28-2023

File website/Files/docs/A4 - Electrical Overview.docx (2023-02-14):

# Electrical Overview

# Year: 2023 Semester: Spring Team: 18 Project: RDNT

# Creation Date: 31 January 2023 Last Modified: 31 January 2023

# Author: Avik Wadhwa Email: wadhwa13@purdu.edu

# Assignment Evaluation:

Item | Score (0-5) | Weight | Points | Notes

Assignment-Specific Items
Electrical Overview | | x3
Electrical Considerations | | x3
Interface Considerations | | x3
System Block Diagram | | x3

Writing-Specific Items
Spelling and Grammar | | x2
Formatting and Citations | | x1
Figures and Graphs | | x2
Technical Writing Style | | x3
Total Score

# 5: Excellent 4: Good 3: Acceptable 2: Poor 1: Very Poor 0: Not attempted

# General Comments:

# Relevant overall comments about the paper will be included here

# 1.0 Electrical Overview

In your functional specification, your team described the desired/expected functionality of your design. In this section, describe the implementation of that functionality from a hardware perspective. What TYPES of chips, sensors, devices, etc. do you expect to use? (note: these are broad categories, and not specific parts. Don’t provide part numbers here; simply describe the categories of parts (e.g. 16-bit microcontroller, pressure sensor, SD card, etc.) What data is being collected and transmitted by the various devices in your system? What software computations and algorithms are being performed in your design? (e.g. “Our DSP will be used to perform a 16-point FFT while the microcontroller will be used for general computing”) That information should be included here.

We will use an ESP32 microcontroller.

In order to power our entire device (including LED strips), we will need an AC/DC wall converter from 120V 60Hz to 12V.

We will need a voltage regulator to drop 12V to 5V (for LEDs) and to 3.3V (for microcontroller).

We will use an microphone to receive audio input.

We will use an op-amp to amplify the microphone input.

We will use an op-amp to smoothen the microphone input.

We will use an op-amp to filter noise from the microphone input.

We will use an AUX module to receive audio input.

We will use an RC filter to smoothen the AUX input.

We will use button controls to switch audio input device between microphone and AUX.

The microcontroller will be used for all computing including reading inputs on the ADC, noise reduction on the input, FFT operations, and sending messages to the LED strips.

In terms of data, we will have analog audio signals inputted from AUX-in or microphone that will be read on the ADC. This will be converted into an array values which will be used in the noise reduction program. After noise reduction, the output music values will be fed into the FFT operations. We will also have digital signals from our bluetooth connection, which will act as external controls for the LEDs.

# 2.0 Electrical Considerations

# This section details design considerations related to the purely electrical aspects of your project. Particular items of interest include:

# The operating frequency(ies) used in your system, and justifications for this(these)

# A power budget, listing out various system voltages (3.3V, 5V, etc.). For each system voltage, list out major components, the current that these components draw, and the resulting power consumed by each of your components

# Tolerances: absolute minimum and maximum voltage/current/power limits for your system

# Electrical loading considerations

Microcontroller operating frequencies: 240MHz


LED strip operating frequencies: 800KHz


To provide power to our LED strips, we will use a linear voltage regulator to drop 12V to 5V. We will drop this down to 3.3V with our voltage regulator to power our microcontroller and external ADC module. Our microphone, filtering op-amp, smoothing op-amp all also require 3.3V so we will use this same source for them as well.

# 3.0 Interface Considerations

# This section details the various interfaces utilized in your design (such as USB, UART, I2C, etc.) Relevant information used in this section should include:

# Types of interfaces, and their use

# Data rates for various system interfaces

BLE: Input from mobile device (1Mbps data rate)

PWM: Output to LED device


ADC: Input from Microphone and AUX

GPIO: Input mode switching

# 4.0 Sources Cited:

# Throughout this and other papers, use of the IEEE citation style should be used. Use of embedded hyperlinks for all web-based sources is required. A reference to the IEEE citation style format is provided here (http://www.ieee.org/documents/ieeecitationref.pdf).

“ESP32-WROOM-32 wi-fi 802.11 & bluetooth module - 4MB FLASH,” Grid Connect. [Online]. Available: https://www.gridconnect.com/products/esp32-wroom-32-wi-fi-802-11-bluetooth-module. [Accessed: 04-Feb-2023].

“WS2812B datasheet,” DigiKey. [Online]. Available: https://www.digikey.com/en/datasheets/parallaxinc/parallax-inc-28085-ws2812b-rgb-led-datasheet. [Accessed: 04-Feb-2023].

# Appendix 1: System Block Diagram

# Include a computer-generated (NOT hand drawn) system block diagram of your design here. Include bus widths and interface types where applicable.


https://engineering.purdue.edu/ece477 Page of

ECE 477: Digital Systems Senior Design Last Modified: 01-31-2023

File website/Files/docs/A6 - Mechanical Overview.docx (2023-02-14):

# Mechanical Overview

# Year: 2023 Semester: Spring Team: 18 Project: RDNT

# Creation Date: 11 February 2023 Last Modified: 11 February 2023

# Author: Graeme Usman Email: gusman@purdue.edu

# Assignment Evaluation:

Item | Score (0-5) | Weight | Points | Notes

Assignment-Specific Items
Commercial Packaging Analysis 1 | | x2
Commercial Packaging Analysis 2 | | x2
CAD Model Illustrations | | x4
Project Packaging Specifications | | x2
PCB Footprint Layout | | x2

Writing-Specific Items
Spelling and Grammar | | x2
Formatting and Citations | | x1
Figures and Graphs | | x2
Technical Writing Style | | x3
Total Score

# 5: Excellent 4: Good 3: Acceptable 2: Poor 1: Very Poor 0: Not attempted

# Comments:

# Comments from the grader will be inserted here.

# 1.0 Commercial Product Packaging

# 1.1 Product #1: IVUDA Audio Visualizer, 14-Segment Music Spectrum Analyzer Kit/Led Acrylic Level Display for Music Lover and Electronic Lover [2]


This design uses an acrylic matrix with LED bulbs placed inside. This allows the “pixelation” of the led bulbs to be hidden. We will use our acrylic sheets to achieve a very similar effect. Their device uses the red/white speaker cables and our device will use AUX-in, microphone, and bluetooth connections. Therefore our device will be easier to interface with. Our display is much larger and will allow for much more customization through our Android app. Particularly, we will allow for multiple color ranges to be selected by the user. The product has 3 knobs for controlling the audio input. This is a nice design and we will consider implementing knobs for external controls.

# 1.2 Product #2: Led Music Spectrum Display Clock, Audio Visualizer,Digital Visualizer Clock with Temperature Display, 7 Spectrum Modes Switch, Music Visualizations Device for Party, Bedroom, Camping [1]


This product features a LED lamp bead grid display. It also features a clock mode and temperature display. This is a very interesting use of space as it can replace the use of a clock in the customer’s home. Our device will feature more customization as the user can customize color ranges beyond this product’s 7 built in modes. Our device will be substantially larger and likely not be placed onto a table/desk like this product. This product has alarms built into its clock functions. We will consider the multiple uses of LED strips beyond just displaying colors.

# 2.0 Project Packaging Description

Our project will consist of two objects. One will be the circuit housing, which will be a project box that we will drill holes into. These holes will allow us to attach audio I/O, external controls, power from a wall adapter, and the male header for our LED strips. The male header will connect to our second object, the LED fixture. This LED fixture will be a large wooden display case with 6 acrylic hollow sections that the LEDs will be located in. We will use 6 acrylic sections to represent the 6 main bands of audible frequencies. The wooden case simply houses the many acrylic sections and provides space to hide the wires. If wood becomes hard to work with, we will consider other options for materials.

# 3.0 Sources Cited

# [1] Bogaert, R. (1980). Audio Spectrum Analyzer. Amazon. Retrieved February 11, 2023, from https://www.amazon.com/Audio-Spectrum-Analyzer/s?k=Audio%2BSpectrum%2BAnalyzer

# [2]Amazon.com - IVUDA Audio Visualizer, 14-Segment Music Spectrum Analyzer ... (n.d.). Retrieved February 12, 2023, from https://www.amazon.com/IVUDA-Visualizer-14-Segment-Spectrum-Electronic/dp/B0BG92X1Q7

# Appendix 1: CAD Model Illustrations


# Note: units are mm.

# Appendix 2: Project Packaging Specifications

Material | Tools Required | Weight | Unit Cost
Frosted Acrylic | Laser Cutter | 3.31 lb. | $ 32.28
Walnut Planks | Hand Saw, Clamps, Wood Glue, Hand Sander | 40-60lb. | $ 32.00
Wood Screws | Hand Drill | 1 lb. | $ 10.99
Wood Glue | Towels, Clamps | 8.96 oz. | $3.29
Dark Wood Stain | Towels, Brushes | 1 quart | $ 12.98
Wood Varnish | Towels, Brushes | 1 quart | $ 23.98
Project Box | Hand Drill | 2 lb. | $ 9.99

# Appendix 3: PCB Footprint Layout


We have the left face categorized by power, operational amplifier, and external peripherals (audio I/O and LEDs). The spacing accounts for decoupling capacitors, amplifier circuitry, and varying trace widths. It is vital to note that LED headers may require larger trace widths, which may likely run through the bottom layer. To account for connection with the voltage regulator, the position of the voltage regulator and MCU may be switched when we move on to adding traces if the connection is causing noise concerns due to the higher expected current in traces to the LED headers.

https://engineering.purdue.edu/ece477 Page of

ECE 477: Digital Systems Senior Design Project Last Modified: 02-11-2023

ECE 477: Digital Systems Senior Design Project v1.1

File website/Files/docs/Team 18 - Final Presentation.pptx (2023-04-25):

## ECE 477 FINAL REVIEW: TEAM #18

PU_sigtab.eps

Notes: Anurag

## OUTLINE

- Project Overview
- Block Diagram
- Design Challenges
- Individual Contributions
- Project Video Demonstration
- Questions

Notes: Anurag

## PROJECT OVERVIEW

RDNT is a device that aims to bring a new dimension to the user’s musical experience, whether it be the main attraction of a party, a fresh new feature to a business’s ambiance, or just to use for the enjoyment of listening to one’s favorite songs in a new way. With multiple avenues to play your favorite tunes, full customization of the LED display’s colors, and control through our mobile app, RDNT intends to create a new dynamic to listening to music as seamless and accessible as possible.


## BLOCK DIAGRAM


## DESIGN CHALLENGES

- Microphone Circuitry
  - Prototyped 4 different amplifier circuits for refined audio
- PCB Design
  - Had to redesign after mid-semester design review
- Power Circuit issues
  - Accidentally designed circuit with tiny capacitors
- FFT Software
  - Difficult to interpret results
- LEDs flickering
  - Had to learn how multiprocessing works in FreeRTOS

## INDIVIDUAL CONTRIBUTIONS

ANURAG NUMBOORI

- Software Prototyping
  - Arduino and ESP-IDF
- Final Firmware Version (with Kahaan)
  - Gaussian Smoothing and ADC Sampling
- Audio Circuitry Design and Prototyping
- Final Schematic (with Graeme and Avik)
- PCB Design (with Avik)
- Display Wiring
- Keeping the team on track

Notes: Anurag

## INDIVIDUAL CONTRIBUTIONS

GRAEME USMAN

- Preliminary Research
  - Helped with finding relevant software, tools, and topics required for our project
- Hardware Prototyping and Testing
  - TMUX prototyping
  - Microphone Amplifier Circuit
- Final Schematic (w/ Anurag and Avik)
- PCB Soldering and Debugging
  - Both final and testing PCBs
- LED Fixture Construction


## INDIVIDUAL CONTRIBUTIONS

Avik Wadhwa

- Preliminary Research and Prototyping
  - Setup of initial schematic – component symbols, footprints
  - Iterations of prototyping circuitry and developing schematic for several components
  - Initial LTspice simulations for Audio circuitry (w/ Kahaan)
- Final Schematic (w/ Anurag and Graeme)
- Final Firmware Version
  - Mode switching software implementation
  - Implementing functionality to perform FFT on audio samples and frequency isolations ( w/ Kahaan and Anurag)
  - Debugging Issues and developing
- PCB Development
  - Development of PCB – planes, layers, traces; based on guidelines from datasheet and Joe (!)
  - Fine tuning PCB based on requirements, and debugging issues (w/ Anurag)
- 3D Modelling for packaging the PCB (w/ Kahaan)

## INDIVIDUAL CONTRIBUTIONS

Kahaan Patel

- Preliminary Research and Prototyping
  - Generating a sample android application using online app simulator
  - Comprehending services needed to configure Bluetooth on ESP32 and Android Respectively
  - Initial LTspice simulations for Audio circuitry (w/ Avik)
- 3D Modelling for packaging the PCB (w/ Avik)
- Final Firmware Version
  - Bluetooth Functionality
  - Implementing functionality to perform FFT on audio samples and frequency isolations ( w/ Avik and Anurag)
  - Implementing Light show post FFT isolation (w/ Anurag)
- Android Application
  - Implementing Bluetooth Class for connection
  - Basic UI for Android Application

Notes: Kahaan

## PROJECT DEMONSTRATION

PSSC #1: The ability to reduce noise on analog inputs through the use of a 1-D Gaussian Filtering algorithm.
PSSC #2: The ability to control and configure multiple connected LED devices through an in-built Bluetooth module that connects with an Android app.
PSSC #3: The ability to amplify and filter analog input of the microphone using a sequence of operational amplifiers.
PSSC #4:The ability for the user to toggle between input modes by using multiplexed external controls. These modes will be Microphone (default), AUX-in, and Bluetooth.
PSSC #5:The ability to drive multiple WS2812B LED strips with PWM signals and reactively display patterns in response to audio signals.
Stretch Goal #1: The ability to isolate frequencies using the FFT algorithm.

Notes: Anurag

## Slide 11

Questions?

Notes: All

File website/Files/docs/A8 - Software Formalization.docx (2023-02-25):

# Software Formalization

# Year: 2023 Semester: Spring Team: 18 Project: RDNT

# Creation Date: February 18, 2023 Last Modified: February 18, 2023

# Author: Kahaan Patel Email: pate1410@purdue.edu

# Assignment Evaluation:

Item | Score (0-5) | Weight | Points | Notes

Assignment-Specific Items
Third Party Software | | x2
Description of Components | | X3
Testing Plan | | x3
Software Component Diagram | | x4

Writing-Specific Items
Spelling and Grammar | | x2
Formatting and Citations | | x1
Figures and Graphs | | x2
Technical Writing Style | | x3
Total Score

# 5: Excellent 4: Good 3: Acceptable 2: Poor 1: Very Poor 0: Not attempted

# General Comments:

# Relevant overall comments about the paper will be included here

# 1.0 Utilization of Third Party Software

For the following project we will use the following third party libraries:

ESP-DSP component library [1]

- This library has very low level code for digital signal processing with the ESP-IDF framework. Many parts of the library are optimized for computation on the ESP32 chip.
- We will use this library for FFT calculation. This has FFT calculations optimized for our chip so we can very quickly sample and isolate frequencies.
- This does not require any attribution or licensing.

ESP32_LED_STRIP component library [2]

- This library has streamlined processes to control the PWM waves required to drive the LEDS. This will make our job much easier when taking frequencies from the FFT operations.
- This does not require any attribution or licensing.

# 2.0 Description of Software Components

We will complete all sampling of input analog signals using our ADC. We are using the Continuous Mode Driver API that is native to the ESP-IDF. We are using the API with custom configuration. The fields that we are configuring include the size of each sample frame, the size of the total sample buffer, the callback that will be called when the ADC has completed filling a sample frame.

The main firmware that will be run on our microcontroller is the FFT algorithm from the ESP-DSP library, a component library of the ESP Framework. This will be used as the backbone for our analog signal processing, which then translates input signals into commands to send to the LEDs. We are using this library without substantial changes but configuring to the sample configurations used by the ADC driver.

The Android application used to control the LEDs’ configuration is being developed by our team through using Gatt Profile and UART on ESP32 devices. We will be using the Gatt library on android to establish connection and send/receive messages. Additionally for the color picking tool we would be using guhoang:colorpicker. This will be used on the user side to choose colors and set a static color on the led strips. Other than that we will be utilizing the standard library to set pages and buttons for user input and onClick listeners for implementing actions.

To summarize :

The Android app, the firmware for the microcontroller, and the signal processing algorithms make up the project's three core software components.

Android App: The Android app is in charge of controlling the user interface and giving the user a way to communicate with the system. The onboard analog microphone, an AUX-in port, and a Bluetooth signal are the three various audio sources that can be chosen by the user. The software will also provide the user the option to choose from a variety of designs and color palettes for the LED strips. The software will accomplish this by utilizing a variety of Android components, including activities, fragments, and views, and Bluetooth to connect with the microcontroller.

Microcontroller Firmware: The firmware of the microcontroller is in charge of reading input samples from the chosen audio source and applying the signal processing algorithms to them. It will read the input signal using an analog-to-digital converter (ADC) and reduce noise. After that, it will separate frequencies from the signal using an FFT technique. The microcontroller will use this processed data to transmit messages to a message sender, which will then operate the LED strips using the FFT output. Also, the microcontroller will control the logic for switching between modes and utilize Bluetooth to connect with the Android app.

Signal Processing Algorithms: The signal processing algorithms are in charge of lowering the input sample's noise level and separating the signal's frequencies. By combining the input signal with a Gaussian function, the 1-D Gaussian filter lowers noise on the signal. The noise-reduced signal is subsequently transformed from the time domain to the frequency domain by the FFT technique. By providing PWM signals to the data port of the LED strips, the microcontroller drives the LED strips using this frequency data.

In conclusion, the Android app connects to the microcontroller over Bluetooth and offers the user interface. The firmware of the microcontroller reads input samples from the chosen audio source, applies signal processing algorithms to them, and then manages the LED strips. The Gaussian filter and FFT method are used in the signal processing algorithms to remove noise from the input sample and separate frequencies from the signal.

# 3.0 Testing Plan

1. To test our ADC Continuous Mode Driver we will connect our ADC input pin to multiple DC signals from the AD2 wave generator. Then we will compare the mean of many samples (multisampling) to confirm that our sample frames have readings acceptable to our signals. We must test the ADC driver first because without correct voltage readings, nothing sent to the FFT operations will be accurate, regardless of the correctness of the FFT operations.
2. FFT will be tested thoroughly, starting by sending in a controlled analog signal generated by an AD2. Using this, we will know what the FFT should find as the fundamental frequency and return that value. Once we have proven that the FFT can handle a single constant sine wave, we can set the AD2 to sweep through a range of frequencies and see if it can handle transitions between frequencies. After this has been proven to work, we can move onto sending analog signals through the AUX jack or Microphone. This will get the algorithm to try to react to actual music, which will confirm full functionality of our project.
3. How to test Android App : The features excluding ESP32 will be tested using the simulator and making sure the button and components that work on click are responding. To check the connection , we will be setting up the bluetooth services on both sides and ensure the messages are sent and received for both the APP and device. Other then that:
  a. Test the app's user interface to see if it is simple to use and intuitive.
  b. To make the app more user-friendly, gather user feedback.
  c. To guarantee that it functions on all supported devices, test the app on several Android devices.
  d. To make sure the app is compatible with all Android versions, test it on various Android versions.
  e. Check the app's response and load times to make sure they are quick and responsive.
  f. To make sure the software is not consuming excessive amounts of memory, test its memory use.
  g. To make sure that user data is secure, test the app's data encryption.
  h. To make sure that only users who have been given permission may use the app's features, test the app's authentication and authorization.
  i. This testing plan, in its entirety, involves testing each project component to ensure that it is operating as intended and that the software is user-friendly, compatible, quick, and secure.

# 4.0 Sources Cited:

# [1] “Espressif DSP Library,” ESP-DSP Library — Espressif DSP Library v1.2.0-17-g94321ab documentation. [Online]. Available: https://espressif-docs.readthedocs-hosted.com/projects/esp-dsp/en/latest/index.html. [Accessed: 18-Feb-2023].

[2]L. Bruder, “Lucas-Bruder/ESP32_LED_STRIP: ESP32 led Strip Library,” GitHub. [Online]. Available: https://github.com/Lucas-Bruder/ESP32_LED_STRIP. [Accessed: 18-Feb-2023].

[3] Android Developers. "BluetoothGatt | Android Developers," September 29, 2021. https://developer.android.com/reference/android/bluetooth/BluetoothGatt.

[4] Android Developers. "BluetoothAdapter | Android Developers," September 29, 2021. https://developer.android.com/reference/android/bluetooth/BluetoothAdapter.

# Appendix 1: Software Component Diagram

# Use this appendix to provide a diagram of the software components of your design. Depending on the nature of your design, multiple software component diagrams or function call structures may be appropriate.


https://engineering.purdue.edu/ece477 Page of

ECE 477: Digital Systems Senior Design Last Modified: 03-03-2015

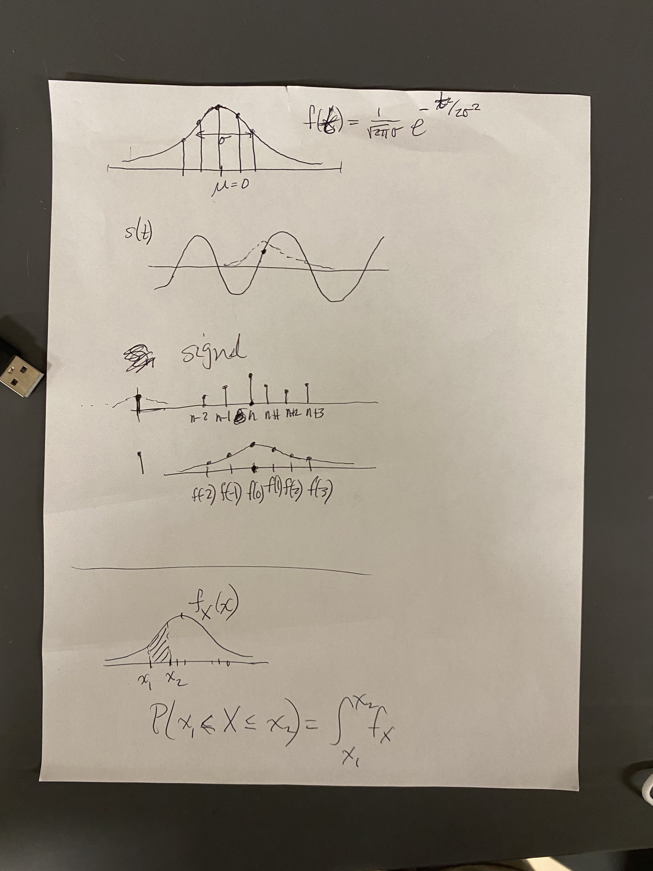
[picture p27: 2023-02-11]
website/Team/progress/progress1pics/gausspaper.jpg

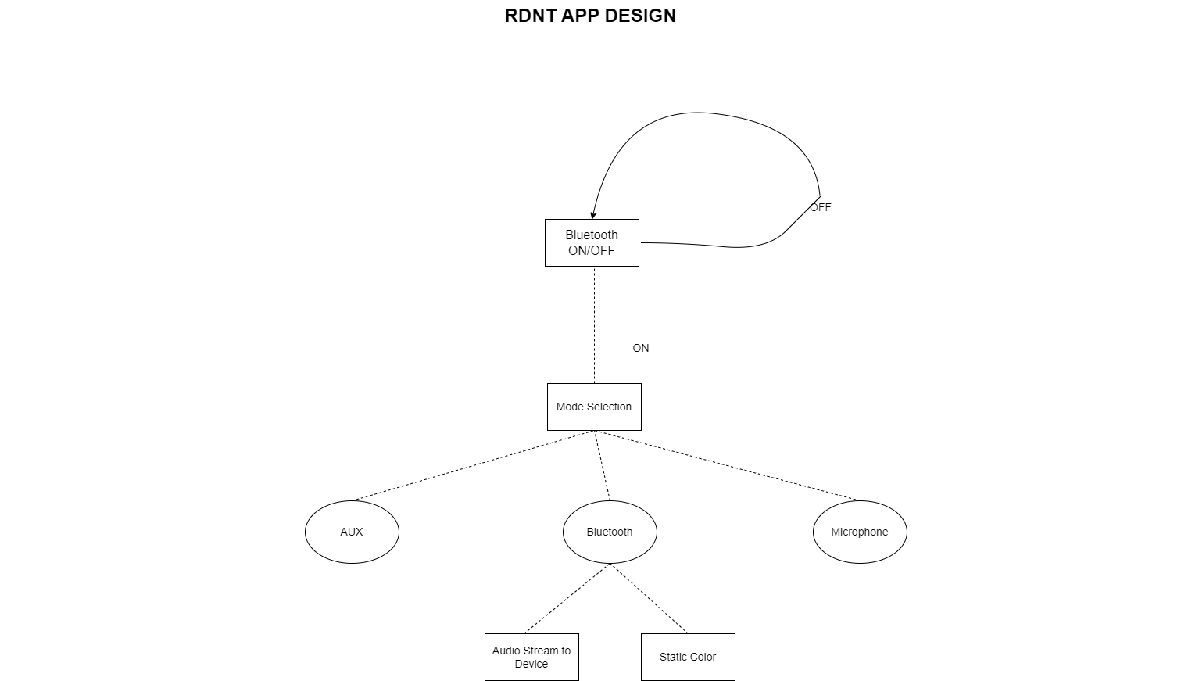
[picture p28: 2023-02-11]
website/Team/progress/resources4/AppDesign.drawio.png

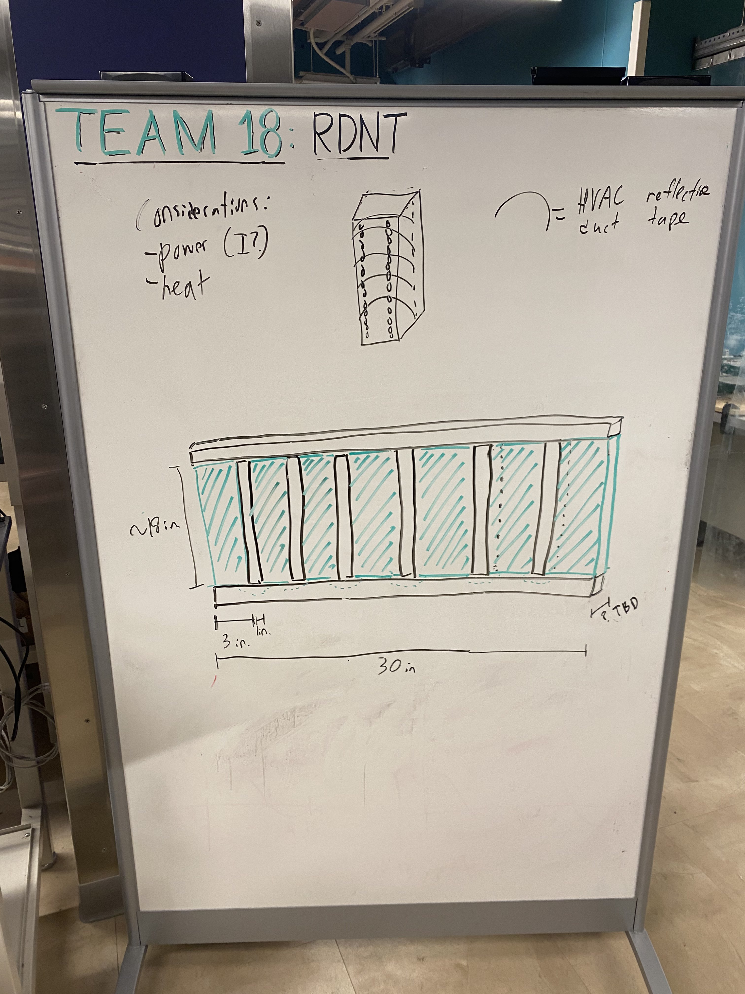
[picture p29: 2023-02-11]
website/Team/progress/progress2pics/LED_fixture_design.jpg

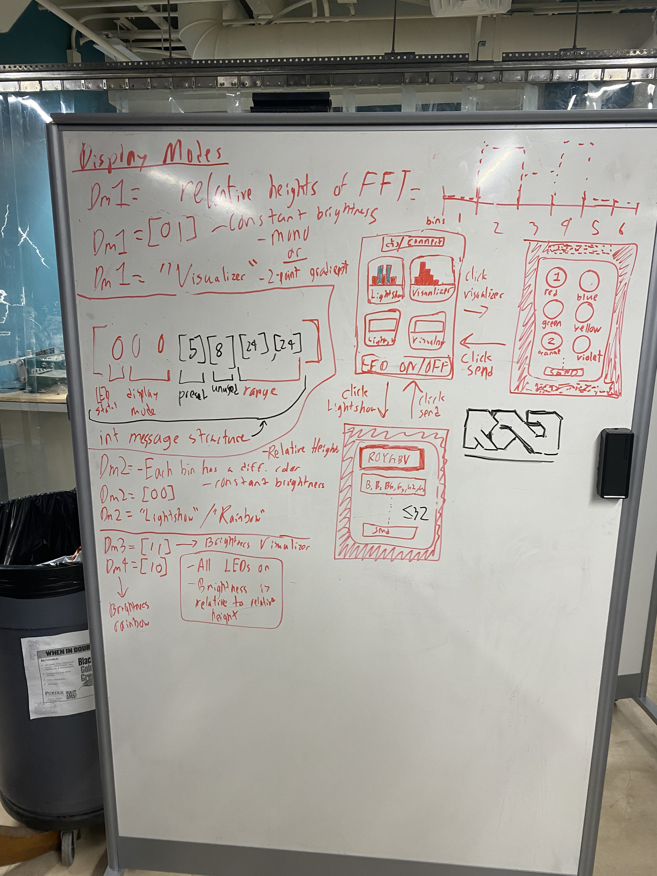
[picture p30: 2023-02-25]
website/Team/progress/progress1pics/appdesign.jpg

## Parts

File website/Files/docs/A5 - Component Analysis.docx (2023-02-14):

# Component Analysis

# Year: 2023 Semester: Spring Team: 18 Project: RDNT

# Creation Date: 31 January 2023 Last Modified: 31 January 2023

# Team Members (#1 is Team Leader):

# Member 1: Anurag Numboori Email: anumboor@purdue.edu

# Member 2: Graeme Usman Email: gusman@purdue.edu

# Member 3: Avik Wadhwa Email: wadhwa13@purdue.edu

# Member 4: Kahaan Patel Email: pate1410@purdue.edu

# Assignment Evaluation:

Item | Score (0-5) | Weight | Points | Notes

Assignment-Specific Items
Analysis of Component 1 | | x2
Analysis of Component 2 | | x2
Analysis of Component 3 | | x2
Bill of Materials | | x6

Writing-Specific Items
Spelling and Grammar | | x2
Formatting and Citations | | x1
Figures and Graphs | | x2
Technical Writing Style | | x3
Total Score

# 5: Excellent 4: Good 3: Acceptable 2: Poor 1: Very Poor 0: Not attempted

# General Comments:

# Relevant overall comments about the paper will be included here

# IMPORTANT NOTE: This team assignment (Component Analysis) and the Bill of Materials are separate team assignments due in subsequent weeks but will be graded together after both have been submitted. Note the weighting of the Bill of Materials in the rubric above.

# 1.0 Component Analysis:

The major components of our design include a Microcontroller, an External ADC, an External Microphone, and strips of LEDs. The design can take audio input heard by the Microphone (or an AUX input, depending on the mode chosen; AUX is not discussed in this document due to the trivial nature of choosing an AUX port), which is then sent along as an analog signal. The External ADC processes any analog signal, and converts it to a digital signal sent into the Microcontroller. Our Microcontroller is the heart of our design, being able to interface with the other components and coordinate and control their behavior with one another. The LED strips are used to display the result of the effort of the previous devices, responding to the audio input that is processed by the Microcontroller and translated into patterns displayed by the LEDs.

# 1.1 Analysis of Microcontrollers:

The most important deciding factor when deciding on a Microcontroller to implement was the inclusion of an onboard Bluetooth module. This allows for a third audio input mode, as well as a much simpler process of connecting to our phone. Low-cost was important as we want the total cost of our device to be as low as possible. Previous experience in using the Microcontroller was also considered, but was not a strong decider. The three main families of microcontroller that we considered were the ESP32, ESP8266, and Arduino.

Given that the main function performed by our Microcontroller was processing and audio signal and computing Fast Fourier Transforms, we required a Microcontroller with enough clock speed and onboard memory to process samples and calculate in as close to real-time as we could. Given these requirements, as well as having included Bluetooth functionality made the ESP32 the best choice.

| ESP32 | ESP8266 | Arduino
Clock Speed | 80MHz - 240Mhz | 52MHz | 16 MHz
Wi-Fi/Bluetooth | Yes/Yes | Yes/No | Yes/Yes*
Flash Memory | 4 MB | 4 MB | 32-256 KB
SRAM | 520 KB | n/a | 2-8 KB
EEPROM | n/a** | 512 Bytes | 1024 Bytes
SPI/I2C/I2S/UART | 2/1/2/2 | 4/2/2/2 | 1/1/1/1
Price | $11.00 | $6.00 | $22.00+

* Wi-Fi/Bluetooth available only on the Arduino MKR1000

** Simulated by Flash Memory

# 1.2 Analysis of OmniDirectional Microphone:

Choosing a good omni-directional microphone has a direct influence on the quality of LED output. The quality of input audio directly affects the accuracy and reactivity of our LED show. There are several areas where this quality could be degraded, like during noise reduction, filtering, and fourier transform. Not only must we focus on minimizing losses, we must start with a microphone that is aligned with the purposes of our application and would be useful in the environmental conditions of our device.

| MAX9814 | CMA-4544PF-W | AOM-5035L-HD3-LW100-R
Signal to Noise Ratio [SNR] A-Weighted (dBA) | 64 | 60 | 75
Current Consumption (mA) | 3.1 | 0.5 | 0.6
Senstivity (dB) | -42 | -44 | -35
Frequency Range [Hz] | 20-20000 | 20-20000 | 20-20000
Maximum Sound Pressure Level [SPL] (dB) | 110 | 94 | 135
Cost ($) | 7.95 | 0.78 | 4.45

The MAX9814 has an inbuilt op-amp with automatic gain control, making it a good choice for hobbyists. However, this feature is not a significant factor as we can focus on creating our own op-amp more economically and with a better microphone to produce more useful audio signals.

We will be using the AOM-5035L-HD3-LW100-R for microphone input. It provides a very good audio input at a reasonal price. Moreover, since we are considering applications where both noise and sound level may be high and the SPL is also critical, we need to implement a microphone that has a slightly lower sensitivity and high SPL and SNR values.

https://www.cuidevices.com/product/resource/cma-4544pf-w.pdf

https://api.puiaudio.com/file/6c8b525b-a9f7-4b7d-827f-f816aaf4768a.pdf

https://cdn-shop.adafruit.com/datasheets/MAX9814.pdf

# 1.3 Analysis of LED Strips:

The LEDs are the final component of our design that ties everything else together, since they are the nexus of all the other components and their operations. The LEDs are meant to synchronize to the beat of certain instruments or sounds by flashing certain patterns and colors, so when considering LED strips, the main requirements were a full range of color and the ability to individually control each LED on the strip, ideally through the microcontroller directly. Other technical specifications, such as electrical requirements or thermal output were factors that we felt were able to be fulfilled once we confirmed the LEDs’ ability to be individually addressed.

We quickly decided on the WS2812B LED strip due to its wide usage and popularity, cost effectiveness, and scalability with multiple strips.

# 2.0 Sources Cited:

“Adafruit AGC Electret microphone amplifier - MAX9814.” [Online]. Available: https://cdn-learn.adafruit.com/downloads/pdf/adafruit-agc-electret-microphone-amplifier-max9814.pdf. [Accessed: 05-Feb-2023].

“Addressable led strip lights,” SuperLightingLED.com Online Store. [Online]. Available: https://www.superlightingled.com/addressable-led-strip-lights-c-5.html. [Accessed: 04-Feb-2023].

“AOM-5035L-HD3-LW100-R Datasheet,” 21-Jun-2021. [Online]. Available: https://api.puiaudio.com/file/6c8b525b-a9f7-4b7d-827f-f816aaf4768a.pdf. [Accessed: 04-Feb-2023].

Cdaviddav, P. Himaja, B. Malik, A. Shukla, Ben, K. Baltus, Elle, Eswar, and L. Boyer, “Arduino vs ESP8266 vs ESP32 microcontroller comparison,” DIYI0T, 07-May-2021. [Online]. Available: https://diyi0t.com/technical-datasheet-microcontroller-comparison/. [Accessed: 04-Feb-2023].

“Esp32 vs Arduino: The main differences,” All3DP, 04-Jan-2023. [Online]. Available: https://all3dp.com/2/esp32-vs-arduino-differences/. [Accessed: 04-Feb-2023].

“ESP32-Wroom-32 Datasheet.” [Online]. Available: https://www.espressif.com.cn/sites/default/files/documentation/esp32-wroom-32_datasheet_en.pdf. [Accessed: 05-Feb-2023].

“Model: CMA-4544PF-W | Description: Electret condenser microphone.” [Online]. Available: https://www.cuidevices.com/product/resource/cma-4544pf-w.pdf. [Accessed: 05-Feb-2023].

“Technical reference manual - ESPRESSIF.” [Online]. Available: https://www.espressif.com/sites/default/files/documentation/esp32_technical_reference_manual_en.pdf. [Accessed: 05-Feb-2023].

“WS2812B datasheet,” DigiKey. [Online]. Available: https://www.digikey.com/en/datasheets/parallaxinc/parallax-inc-28085-ws2812b-rgb-led-datasheet. [Accessed: 04-Feb-2023].

https://engineering.purdue.edu/ece477 Page of

ECE 477: Digital Systems Senior Design Last Modified: 1-31-2023

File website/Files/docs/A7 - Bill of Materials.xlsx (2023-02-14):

ECE477 Bill of Materials v1.0
Year: | 2023 | Semester: |  | Spring | Project Name: | RDNT
Author: | Anurag Numboori
Created: | 2023-02-11
Last Modified: | 2023-02-11
Project_Component |  |  |  |  |  |  |  | Qty:
Description | ID | Qty | Value | Package | Manufacturer | Mfg. Part # | Supplier | Supplier Part #
PCB | - | 1 | - | Off-Board | Digikey | - | - | -
Project Box A | - | 1 | 3.94"x2.68"x1.97"(2Pcs) | Off-Board | Otdorpatio | - | Amazon | B08N6P4HPH
Project Box B | - | 1 | 6.3"x4.33"x3.54" | Off-Board | Otdorpatio | - | Amazon | B09B6QJNYD
TRRS Jack | 35RAPC5CHWNSN | 2 | 3.5mm | Tray | Switchcraft Inc. | 35RAPC5CHWNSN | Digikey | 137-35RAPC5CHWNSN-ND
Electret Microphone | AOM-5035L-HD3-LW100-R | 3 | - | Tray | PUI Audio, Inc. | AOM-5035L-HD3-LW100-R | Digikey | 668-AOM-5035L-HD3-LW100-R-ND
Button | JST1103ST-2 | 4 | - | Spool | JS SWITCH | JST1103ST-2 | Digikey | 4274-JST1103ST-2-ND
Op-Amp | LM324EDR2G | 2 | - | TR | Onsemi | LM324EDR2G | Digikey | LM324EDR2GOSTR-ND - Tape & Reel (TR)
Linear Power Regulator | LT1117CM-3.3#PBF | 2 | - | Tube | Analog Devices Inc. | LT1117CM-3.3#PBF | Digikey | 505-LT1117CM-3.3#PBF-ND
Microcontroller | ESP32 | 2 | - | Surface Mount | Espressif Systems | ESP32-WROOM-32D-N16 | Digikey | 1965-ESP32-WROOM-32D-N16DKR-ND
16 ft. LED Strips | ‎WS2812B5M60LW30 | 2 | 16.4FT 60Pixels/m 300Pixels | Off-Board | BTF-LIGHTING | WS2812B5M60LW30 | Amazon | B01CDTEG1O
Barrel Power Jack | PJ-030DH-SMT-TR | 2 | 1.3mm | Surface Mount | CUI Devices | PJ-030DH-SMT-TR | Digikey | CP-030DHPJ-TR-ND
Frosted Acrylic | - | 1 | 24 in. x 36 in. x 0.100 in. | Off-Board | Plaskolite | - | Home Depot | -
Walnut Planks | - | 2 | 1 in. x 6 in. x 2 ft. | Off-Board | Home Depot | - | Home Depot | -
Wood Screws | - | 1 lb. | 3 in. | Off-Board | Grip-Rite | - | Home Depot | -
Wood Glue | - | 2 | 8 oz. | Off-Board | Titebond | - | Home Depot | -
Dark Wood Stain | - | 1 | 1 qt. | Off-Board | Varathane | - | Home Depot | -
Varnish | - | 1 | 1 qt. | Off-Board | Olympic | - | Home Depot | -

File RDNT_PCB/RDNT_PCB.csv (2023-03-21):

Source: | C:\Users\pcadm\Documents\GitHub\RDNT\RDNT_PCB\RDNT_PCB.kicad_sch
Date: | 3/21/2023 9:18
Tool: | Eeschema (6.0.11)
Generator: | C:\Program Files\KiCad\6.0\bin\scripting\plugins/bom_csv_grouped_by_value_with_fp.py
Component Count: | 52
Ref | Qnty | Value | Cmp name | Footprint | Description | Status | Quantity | Link
C1, C2, C4, C5, C11, C12, | 6 | 0.1uF | C | Capacitor_SMD:C_1206_3216Metric | Unpolarized capacitor
C3, C9, C10, | 3 | 10uF | C | Capacitor_SMD:C_1206_3216Metric | Unpolarized capacitor
C6, | 1 | .1uF | C | Capacitor_SMD:C_1206_3216Metric | Unpolarized capacitor
C7, | 1 | 1uF | C | Capacitor_SMD:C_1206_3216Metric | Unpolarized capacitor
C8, | 1 | 0.033uF | C | Capacitor_SMD:C_1206_3216Metric | Unpolarized capacitor
C13, | 1 | .01uF | C | Capacitor_SMD:C_1206_3216Metric | Unpolarized capacitor
C_boot1, | 1 | GRM155R71A104KA01D | GRM155R71A104KA01D | TPS563300_Power_Circuit:C_Boot_CAPC1005X55N |  | Filled
C_in1, | 1 | GRM31CR71E106KA12L | GRM31CR71E106KA12L | TPS563300_Power_Circuit:C_IN_CAPC3216X180N |  | Filled
C_inx1, | 1 | GRM155R71A104KA01D | GRM155R71A104KA01D | TPS563300_Power_Circuit:C_Boot_CAPC1005X55N |  | Filled
C_out1, | 1 | GRM32EC80J107ME20L | GRM32EC80J107ME20L | TPS563300_Power_Circuit:C_OUT_CAPC3225X270N | Murata 1210 GRM 100uF Ceramic Multilayer Capacitor, 6.3 V dc, +105C, X6S Dielectric, +/-20% SMD | Filled
H2, H3, H4, H5, | 4 | MountingHole | MountingHole | MountingHole:MountingHole_3.2mm_M3 | Mounting Hole without connection
IC1, | 1 | TPS563300DRLR | TPS563300DRLR | TPS563300_Power_Circuit:TPS563300DRLR | TPS563300 3.8-V to 28-V, 3-A Synchronous Buck Converter in SOT583 Package | Filled
J1, | 1 | Conn_ARM_JTAG_SWD_10 | Conn_ARM_JTAG_SWD_10 | Connector_PinHeader_1.27mm:PinHeader_2x05_P1.27mm_Vertical_SMD | Cortex Debug Connector, standard ARM Cortex-M SWD and JTAG interface
J5, J6, | 2 | Screw_Terminal_01x03 | Screw_Terminal_01x03 | Connector_Phoenix_MSTB:PhoenixContact_MSTBA_2,5_3-G-5,08_1x03_P5.08mm_Horizontal | Generic screw terminal, single row, 01x03, script generated (kicad-library-utils/schlib/autogen/connector/)
J_in1, | 1 | AudioJack3 | AudioJack3 | Connector_Audio:Jack_3.5mm_CUI_SJ-3523-SMT_Horizontal | Audio Jack, 3 Poles (Stereo / TRS) | Filled
J_out1, | 1 | AudioJack3 | AudioJack3 | Connector_Audio:Jack_3.5mm_CUI_SJ-3523-SMT_Horizontal | Audio Jack, 3 Poles (Stereo / TRS) | Filled
L1, | 1 | HCM0703-4R7-R | HCM0703-4R7-R | TPS563300_Power_Circuit:L1_HCM0703-4R7-R |  | Filled
MK2, | 1 | CMA-4544PF-W | CMA-4544PF-W | electret_mic:MIC_CMA-4544PF-W |  | Missing | 1
R1, R2, R15, | 3 | 10000 | R_US | Resistor_SMD:R_1206_3216Metric | Resistor, US symbol
R3, | 1 | 1 | R_US | Resistor_SMD:R_1206_3216Metric | Resistor, US symbol
R4, | 1 | 500 | R_US | Resistor_SMD:R_1206_3216Metric | Resistor, US symbol
R7, | 1 | 203000 | R_US | Resistor_SMD:R_1206_3216Metric | Resistor, US symbol
R8, | 1 | 100000 | R_US | Resistor_SMD:R_1206_3216Metric | Resistor, US symbol
R12, | 1 | 100 | R_US | Resistor_SMD:R_1206_3216Metric | Resistor, US symbol
R17, | 1 | 2200 | R_US | Resistor_SMD:R_1206_3216Metric | Resistor, US symbol
R18, | 1 | 400000 | R_US | Resistor_SMD:R_1206_3216Metric | Resistor, US symbol
R19, | 1 | 100000 | R_US | Resistor_SMD:R_1206_3216Metric | Resistor, US symbol
R20, | 1 | 1000 | R_US | Resistor_SMD:R_1206_3216Metric | Resistor, US symbol
R21, | 1 | 1500 | R_US | Resistor_SMD:R_1206_3216Metric | Resistor, US symbol
R_fbb1, | 1 | CRCW040210K0FKED | CRCW040210K0FKED | TPS563300_Power_Circuit:R_FBB_RESC1005X40N |  | Filled
R_fbt1, | 1 | CRCW060330K9FKEA | CRCW060330K9FKEA | TPS563300_Power_Circuit:R_FBT_RESC1508X50N |  | Filled
SW1, SW2, SW3, | 3 | SW_MEC_5E | SW_MEC_5E | Button_Switch_SMD:SW_MEC_5GSH9 | MEC 5E single pole normally-open tactile switch | Missing | 3
U1, | 1 | ESP32-WROOM-32D | ESP32-WROOM-32D | RF_Module:ESP32-WROOM-32 | RF Module, ESP32-D0WD SoC, Wi-Fi 802.11b/g/n, Bluetooth, BLE, 32-bit, 2.7-3.6V, onboard antenna, SMD | Filled
U2, | 1 | PTMUX1308QDYYRQ1 | PTMUX1308QDYYRQ1 | TMUX1309QDYYRQ1:PTMUX1308QDYYRQ1 |  | Missing | 3
U3, | 1 | LM324 | LM324 | Lm324:LM324D | Low-Power, Quad-Operational Amplifiers, DIP-14/SOIC-14/SSOP-14 | Filled
Power | Filled
Debug and JTAG Switches
Audio_In
MUX

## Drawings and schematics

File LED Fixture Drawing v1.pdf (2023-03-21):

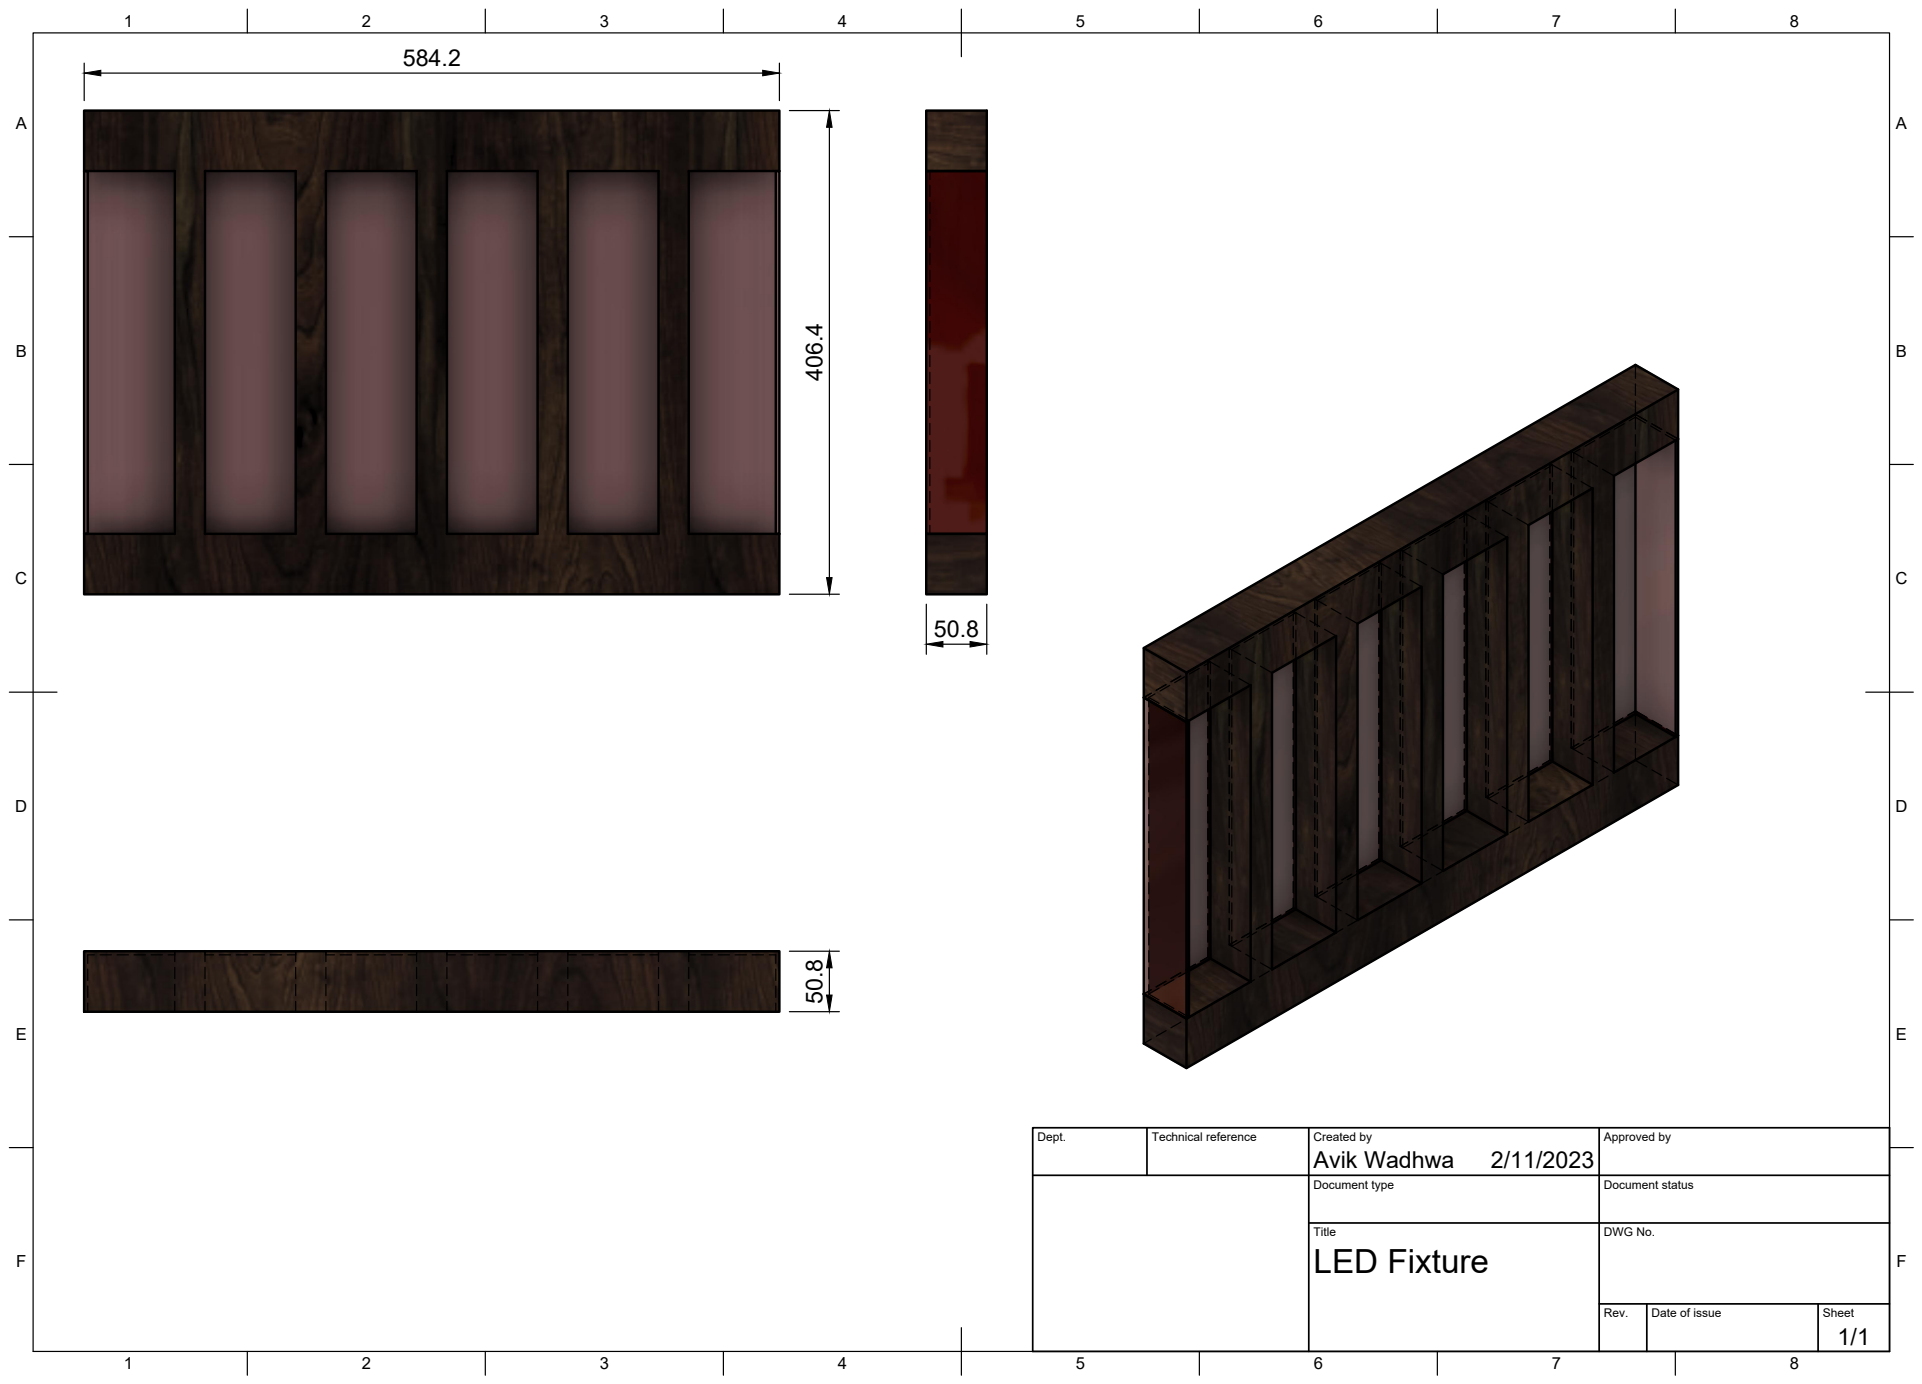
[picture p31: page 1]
Title; DWG No.; Rev.; Date of issue; Sheet; LED Fixture

Dept. | Technical reference | Created by Avik Wadhwa 2/11/2023 | Approved by

Document type | Document status

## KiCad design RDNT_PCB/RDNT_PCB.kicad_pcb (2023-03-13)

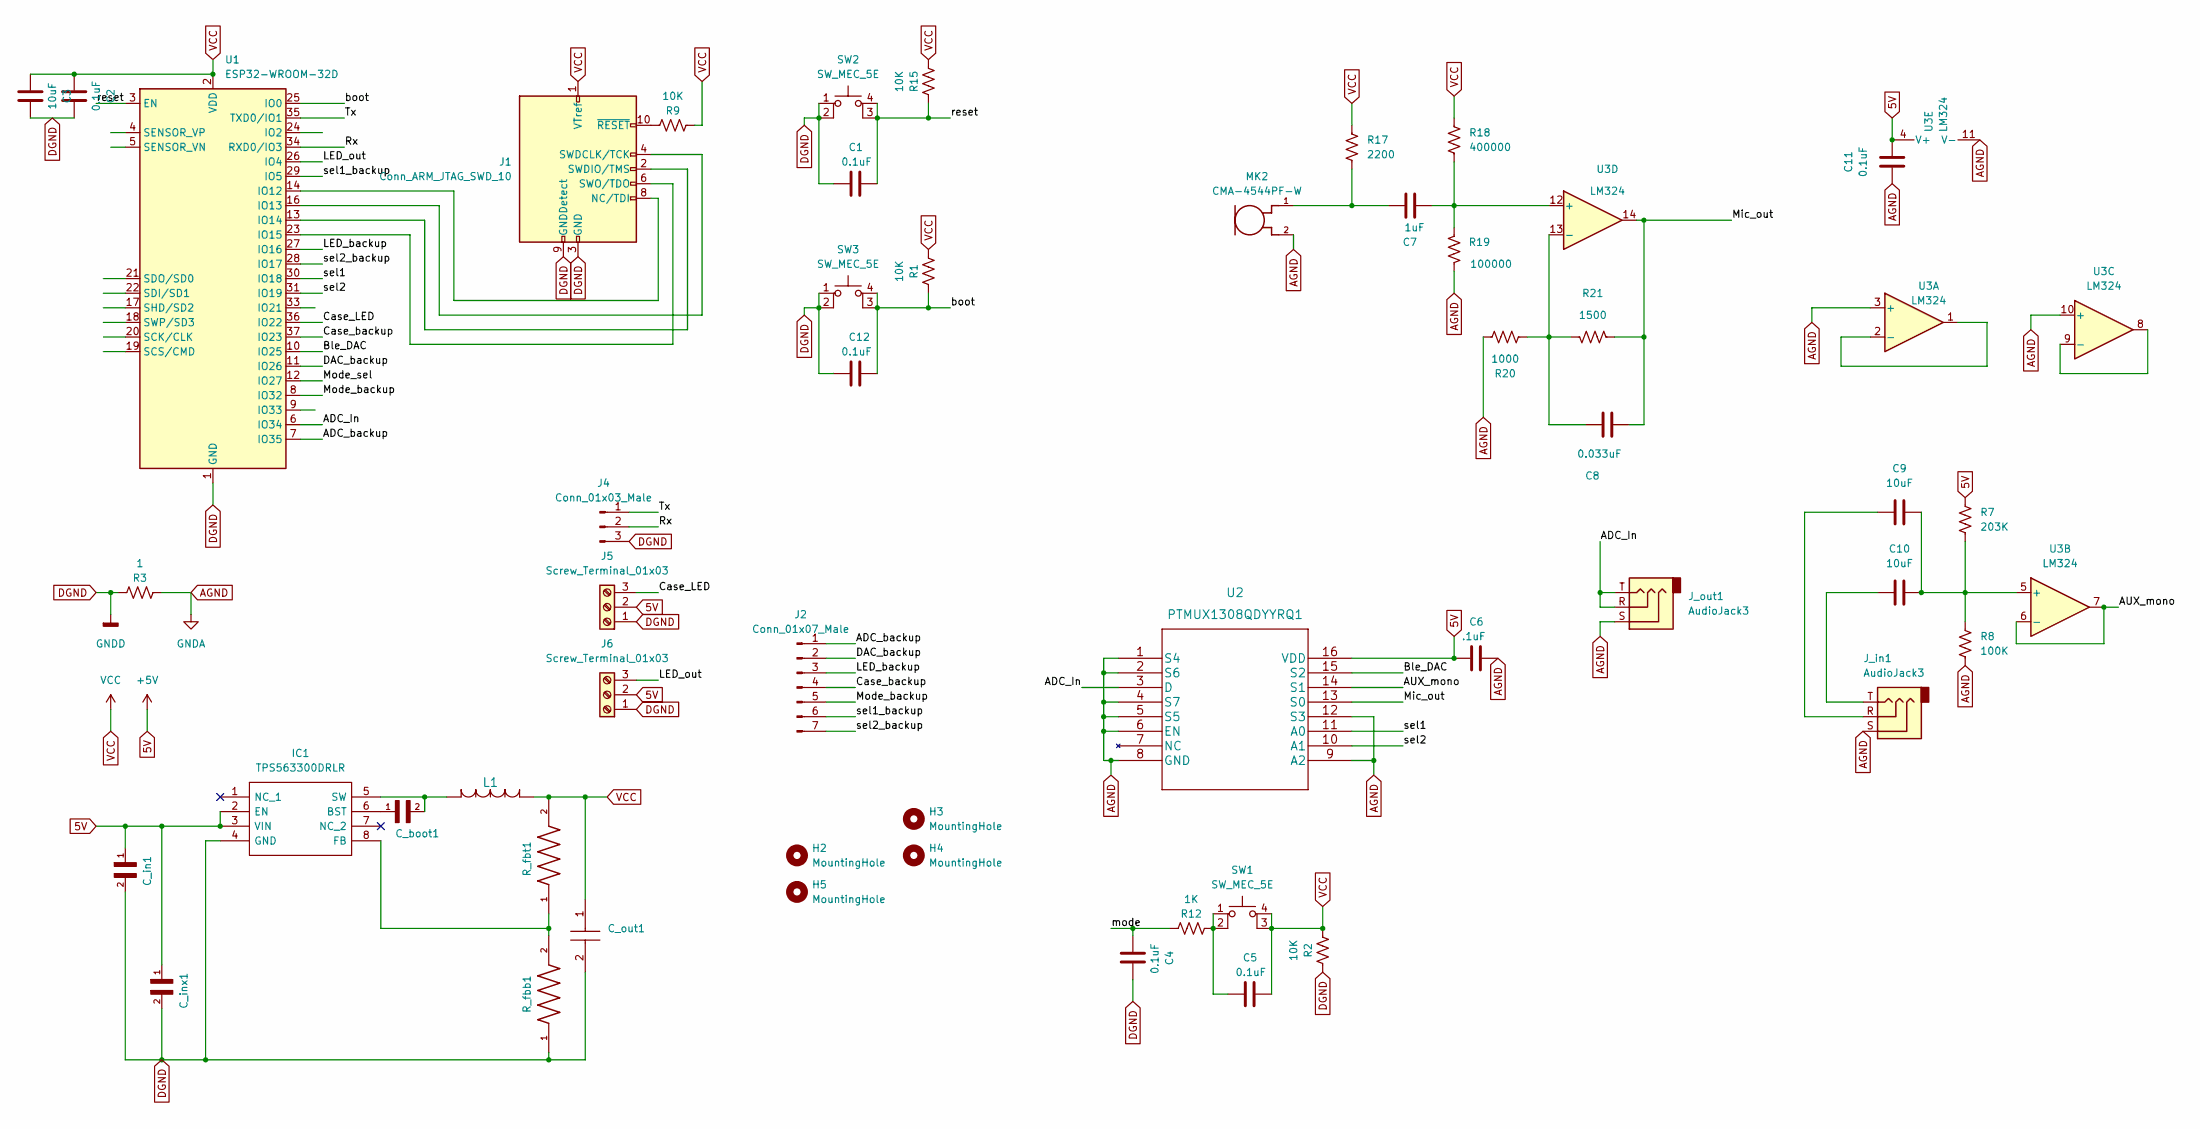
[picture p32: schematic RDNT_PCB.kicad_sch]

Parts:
C1, C2, C4, C5, C11, C12: 0.1uF; C_1206_3216Metric
C3, C9, C10: 10uF; C_1206_3216Metric
C6: .1uF; C_1206_3216Metric
C7: 1uF; C_1206_3216Metric
C8: 0.033uF; C_1206_3216Metric
C_boot1: GRM155R71A104KA01D; C_Boot_CAPC1005X55N
C_in1: GRM31CR71E106KA12L; C_IN_CAPC3216X180N
C_inx1: GRM155R71A104KA01D; C_Boot_CAPC1005X55N
C_out1: GRM32EC80J107ME20L; C_OUT_CAPC3225X270N; Mouser Part Number 81-GRM32EC80J107ME0L
H2, H3, H4, H5: MountingHole; MountingHole_3.2mm_M3
IC1: TPS563300DRLR; Mouser Part Number 595-TPS563300DRLR
J1: Conn_ARM_JTAG_SWD_10; PinHeader_2x05_P1.27mm_Vertical_SMD
J2: Conn_01x07_Male
J4: Conn_01x03_Male
J5, J6: Screw_Terminal_01x03; PinHeader_1x03_P2.54mm_Vertical
J_in1: AudioJack3; Jack_3.5mm_CUI_SJ-3523-SMT_Horizontal
J_out1: AudioJack3; Jack_3.5mm_CUI_SJ-3523-SMT_Horizontal
L1: HCM0703-4R7-R; L1_HCM0703-4R7-R
MK2: CMA-4544PF-W; MIC_CMA-4544PF-W
R1, R2, R9, R15: 10K; R_1206_3216Metric
R3: 1; R_1206_3216Metric
R7: 203K; R_1206_3216Metric
R8: 100K; R_1206_3216Metric
R12: 1K; R_1206_3216Metric
R17: 2200; R_1206_3216Metric
R18: 400000; R_1206_3216Metric
R19: 100000; R_1206_3216Metric
R20: 1000; R_1206_3216Metric
R21: 1500; R_1206_3216Metric
R_fbb1: CRCW040210K0FKED; R_FBB_RESC1005X40N
R_fbt1: CRCW060330K9FKEA; R_FBT_RESC1508X50N
SW1, SW2, SW3: SW_MEC_5E; SW_MEC_5GSH9
U1: ESP32-WROOM-32D; ESP32-WROOM-32
U2: PTMUX1308QDYYRQ1
U3: LM324; LM324D

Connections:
5V: C6.2, C11.1, C_in1.1, C_inx1.1, IC1.2 (EN), IC1.3 (VIN), J5.2, J6.2, R7.1, U2.16 (VDD), U3.4 (V+)
/ADC_In: J_out1.R, J_out1.T, U1.6 (IO34), U2.3 (D)
/ADC_backup: J2.1, U1.7 (IO35)
/AUX_mono: U2.14 (S1), U3.6 (-), U3.7
/Ble_DAC: U1.10 (IO25), U2.15 (S2)
/Case_LED: J5.3, U1.36 (IO22)
/Case_backup: J2.4, U1.37 (IO23)
/DAC_backup: J2.2, U1.11 (IO26)
/LED_backup: J2.3, U1.27 (IO16)
/LED_out: J6.3, U1.26 (IO4)
/Mic_out: C8.2, R21.1, U2.13 (S0), U3.14
/Mode_backup: J2.5, U1.8 (IO32)
/Mode_sel: U1.12 (IO27)
/Rx: J4.2, U1.34 (RXD0/IO3)
/Tx: J4.1, U1.35 (TXD0/IO1)
/boot: C12.1, R1.2, SW3.3 (K), SW3.4 (A), U1.25 (IO0)
/mode: C4.2, R12.2
/reset: C1.1, R15.2, SW2.3 (K), SW2.4 (A), U1.3 (EN)
/sel1: U1.30 (IO18), U2.11 (A0)
/sel1_backup: J2.6, U1.29 (IO5)
/sel2: U1.31 (IO19), U2.10 (A1)
/sel2_backup: J2.7, U1.28 (IO17)
AGND: C6.1, C11.2, J_in1.S, J_out1.S, MK2.2, R3.1, R8.2, R19.1, R20.1, U2.1 (S4), U2.2 (S6), U2.4 (S7), U2.5 (S5), U2.6 (EN), U2.8 (GND), U2.9 (A2), U2.12 (S3), U3.3 (+), U3.10 (+), U3.11 (V-)
DGND: C1.2, C2.1, C3.1, C4.1, C12.2, C_in1.2, C_inx1.2, C_out1.2, IC1.4 (GND), J1.3 (GND), J1.5 (GND), J1.9 (GNDDetect), J4.3, J5.1, J6.1, R2.2, R3.2, R_fbb1.1, SW2.1, SW2.2, SW3.1, SW3.2, U1.1 (GND), U1.15 (GND), U1.38 (GND), U1.39 (GND)
unnamed: C5.2, R12.1, SW1.1, SW1.2
unnamed: C7.1, MK2.1, R17.2
unnamed: C7.2, R18.2, R19.2, U3.12 (+)
unnamed: C8.1, R20.2, R21.2, U3.13 (-)
unnamed: C9.2, J_in1.R
unnamed: C9.1, C10.1, R7.2, R8.1, U3.5 (+)
unnamed: C10.2, J_in1.T
unnamed: C_boot1.1, IC1.6 (BST)
unnamed: C_boot1.2, IC1.5 (SW), L1.2
unnamed: IC1.8 (FB), R_fbb1.2, R_fbt1.1
unnamed: J1.2 (SWDIO/TMS), U1.13 (IO14)
unnamed: J1.4 (SWDCLK/TCK), U1.16 (IO13)
unnamed: J1.6 (SWO/TDO), U1.23 (IO15)
unnamed: J1.8 (NC/TDI), U1.14 (IO12)
unnamed: J1.10 (~RESET), R9.2
unnamed: U3.1, U3.2 (-)
unnamed: U3.8, U3.9 (-)
VCC: C2.2, C3.2, C5.1, C_out1.1, J1.1 (VTref), L1.1, R1.1, R2.1, R9.1, R15.1, R17.1, R18.1, R_fbt1.2, SW1.3 (K), SW1.4 (A), U1.2 (VDD)

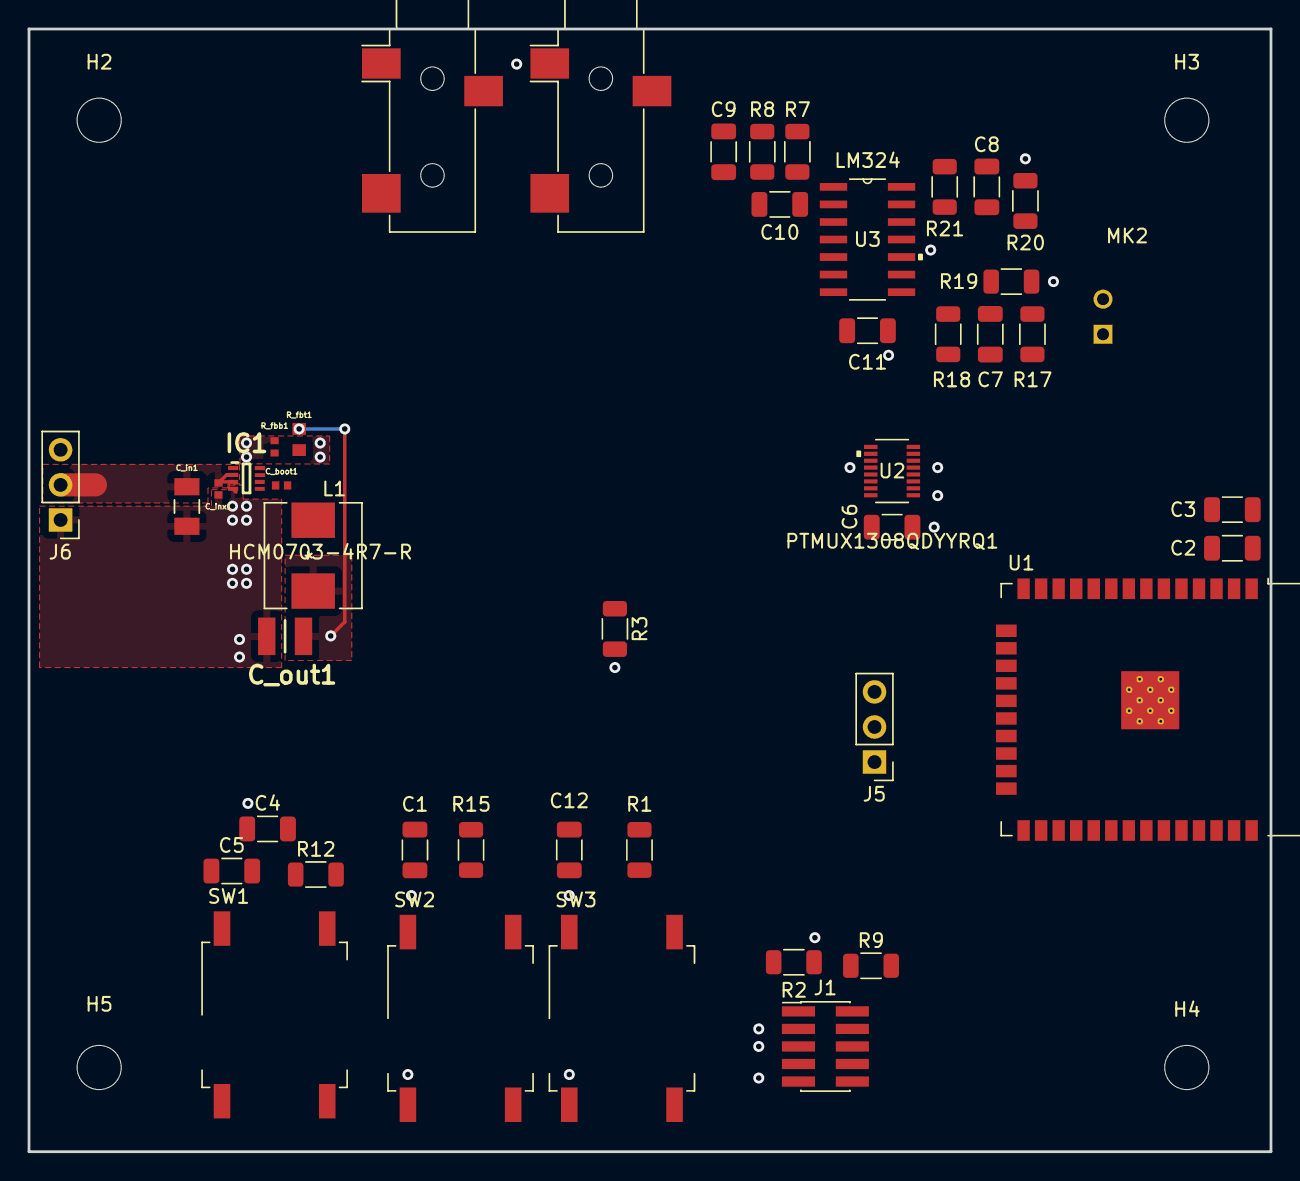
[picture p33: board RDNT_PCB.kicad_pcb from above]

Board: 2 copper layers, 89.9 x 81.3 mm, 49 parts (1 on the bottom side), 32 nets.

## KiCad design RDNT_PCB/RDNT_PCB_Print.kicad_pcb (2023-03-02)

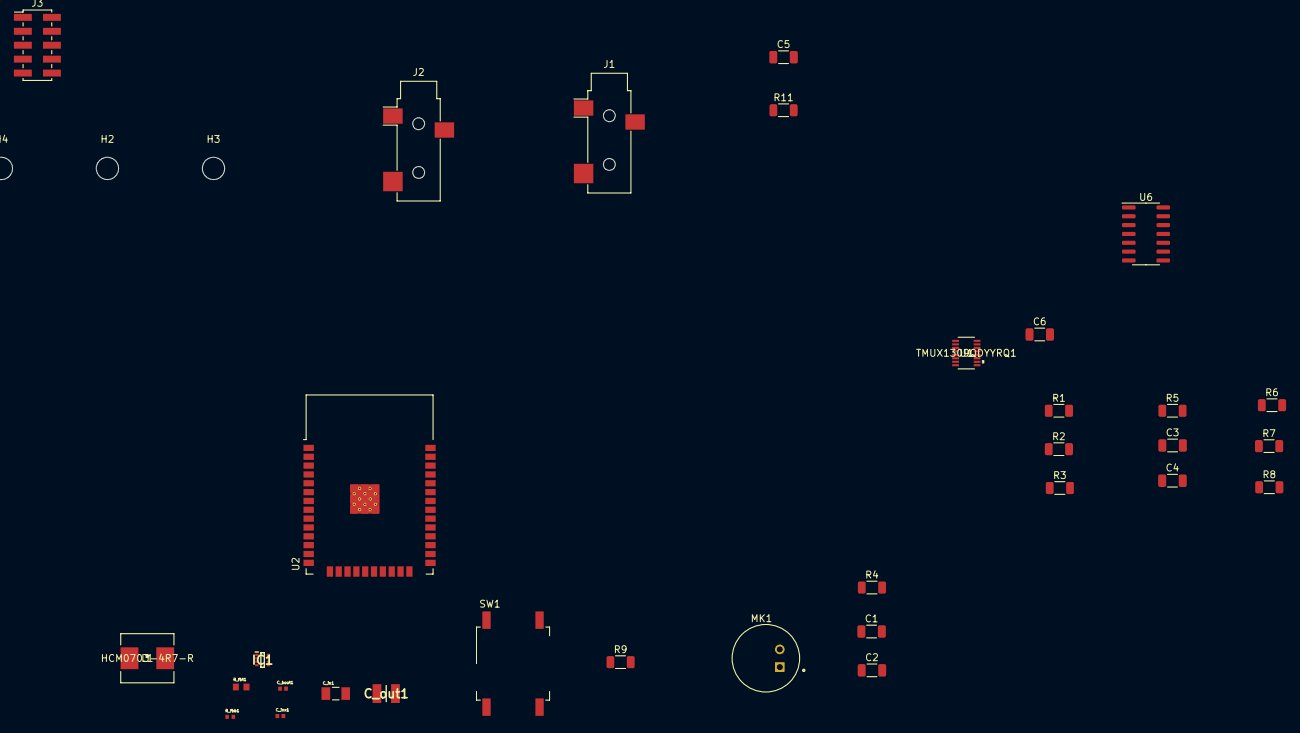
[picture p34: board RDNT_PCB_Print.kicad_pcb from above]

Board: 2 copper layers, 36 parts (0 on the bottom side), 25 nets, no tracks yet.

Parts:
C1: 1uF; C_1206_3216Metric
C2: 470uF; C_1206_3216Metric
C3, C5: 100uF; C_1206_3216Metric
C4: 10uF; C_1206_3216Metric
C6: .1uF; C_1206_3216Metric
C_boot1: GRM155R71A104KA01D; C_Boot_CAPC1005X55N
C_in1: GRM31CR71E106KA12L; C_IN_CAPC3216X180N
C_inx1: GRM155R71A104KA01D; C_Boot_CAPC1005X55N
C_out1: GRM32EC80J107ME20L; C_OUT_CAPC3225X270N
H1, H2, H3, H4: MountingHole; MountingHole_3.2mm_M3
IC1: TPS563300DRLR
J1, J2: AudioJack3; Jack_3.5mm_CUI_SJ-3523-SMT_Horizontal
J3: Conn_02x05_Counter_Clockwise; PinHeader_2x05_P2.00mm_Vertical_SMD
L1: HCM0703-4R7-R; L1_HCM0703-4R7-R
MK1: CMA-4544PF-W; MIC_CMA-4544PF-W
R1, R3: 100K; R_1206_3216Metric
R2, R5, R9: 1K; R_1206_3216Metric
R4: 22K; R_1206_3216Metric
R6, R11: 330; R_1206_3216Metric
R7: 510; R_1206_3216Metric
R8: 110; R_1206_3216Metric
R_fbb1: CRCW040210K0FKED; R_FBB_RESC1005X40N
R_fbt1: CRCW060330K9FKEA; R_FBT_RESC1508X50N
SW1: SW_MEC_5E; SW_MEC_5GSH9
U1: TMUX1309QDYYRQ1
U2: ESP32-WROOM-32
U6: LM324; SOIC-14_3.9x8.7mm_P1.27mm

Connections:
/+3V3: C2.1, C6.2, C_out1.1, J3.2, L1.1, R4.2, R_fbt1.2, SW1.1, U1.16 (VDD), U2.2 (VDD), U6.4 (V+)
/+5V: C_in1.1, C_inx1.1, IC1.3 (VIN), J3.1
/Audio_Out: J1.R, J1.T, J3.3, U1.3 (D)
/Aux_ADC: C5.1, J3.5, R11.1, U1.15 (S2)
/Ble_ADC: J3.4, U1.12 (S3), U2.6 (IO34)
/Mic_ADC: J3.6, R7.1, R8.1, U1.14 (S1), U6.8
/sel1: J3.8, SW1.4 (A), U1.11 (A0), U2.30 (IO18)
/sel2: J3.7, U1.10 (A1), U2.31 (IO19)
unnamed: C1.1, MK1.2, R4.1
unnamed: C1.2, C2.2, C3.2, MK1.1, R2.1, R3.1, R5.1, R6.2, R8.2
unnamed: C3.1, C4.2, U6.7
unnamed: C4.1, R6.1, U6.10 (+)
unnamed: C5.2, J2.T
unnamed: C_boot1.1, IC1.6 (BST)
unnamed: C_boot1.2, IC1.5 (SW), L1.2
unnamed: C_in1.2, C_inx1.2, C_out1.2, IC1.4 (GND), R_fbb1.1
unnamed: IC1.8 (FB), R_fbb1.2, R_fbt1.1
unnamed: J2.R, J2.S, R11.2
unnamed: R1.1, U6.1
unnamed: R1.2, R2.2, U6.2 (-), U6.6 (-)
unnamed: R3.2, U6.3 (+)
unnamed: R5.2, U6.5 (+)
unnamed: R7.2, U6.9 (-)
unnamed: R9.2, SW1.2
unnamed: U2.1 (GND), U2.15 (GND), U2.38 (GND), U2.39 (GND)

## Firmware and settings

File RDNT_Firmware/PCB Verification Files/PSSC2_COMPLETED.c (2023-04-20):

/*
 * SPDX-FileCopyrightText: 2021-2022 Espressif Systems (Shanghai) CO LTD
 *
 * SPDX-License-Identifier: Apache-2.0
 */

#include <string.h>
#include <stdio.h>
#include "sdkconfig.h"
#include "esp_log.h"
#include "freertos/FreeRTOS.h"
#include "freertos/task.h"
#include "freertos/semphr.h"
#include "esp_adc/adc_continuous.h"
#include "driver/gpio.h"

#include <stdlib.h>
#include <inttypes.h>
#include "freertos/event_groups.h"
#include "nvs_flash.h"

#include "esp_system.h"
#include "driver/spi_master.h"
#include "soc/gpio_struct.h"
#include "driver/uart.h"
#include "soc/uart_struct.h"
#include <math.h>

#include "esp_dsp.h"

#include "driver/rmt_tx.h"
#include "led_strip_encoder.h"

#include "esp_bt.h"
#include "esp_gap_ble_api.h"
#include "esp_gatts_api.h"
#include "esp_bt_defs.h"
#include "esp_bt_main.h"
#include "esp_gatt_common_api.h"

#define GPIO_INPUT_27 GPIO_NUM_27
#define GPIO_INPUT_PIN_SEL (1ULL << GPIO_INPUT_27)

#define ESP_INTR_FLAG_DEFAULT 0
#define DEBOUNCE_TIME_MS 100

#define GPIO_OUTPUT_18 GPIO_NUM_18
#define GPIO_OUTPUT_19 GPIO_NUM_19
#define GPIO_OUTPUT_PIN_SEL (1ULL << GPIO_OUTPUT_18 | 1ULL << GPIO_OUTPUT_19)

#define RMT_LED_STRIP_RESOLUTION_HZ 10000000 // 10MHz resolution, 1 tick = 0.1us (led strip needs a high resolution)
#define RMT_LED_STRIP_GPIO_NUM 4

#define LED_QTY 34

#define READ_LEN 512
#define EXAMPLE_ADC_CONV_MODE ADC_CONV_SINGLE_UNIT_1

#define EXAMPLE_ADC_USE_OUTPUT_TYPE1 1
#define EXAMPLE_ADC_OUTPUT_TYPE ADC_DIGI_OUTPUT_FORMAT_TYPE1

static uint32_t last_interrupt_time = 0;

volatile int state;

int led_status = 0;        // start with on mode
int colors[3] = {0, 1, 0}; // grb

static const char *TAG = "EXAMPLE";
#define GATTS_TAG "BLUEETOOTH"

uint8_t result[READ_LEN] = {0};

static uint8_t led_strip_pixels[LED_QTY * 3];

rmt_channel_handle_t led_chan = NULL;
rmt_encoder_handle_t led_encoder = NULL;

static adc_channel_t channel[1] = {ADC_CHANNEL_6}; // PIN number 6 IO34
static TaskHandle_t s_task_handle;

rmt_transmit_config_t tx_config = {
    .loop_count = 0, // no transfer loop
};

static void gatts_profile_event_handler(esp_gatts_cb_event_t event, esp_gatt_if_t gatts_if, esp_ble_gatts_cb_param_t *param);
#define GATTS_SERVICE_UUID 0x00FF
#define GATTS_CHAR_UUID 0xFF01
#define GATTS_NUM_HANDLE 4
#define TEST_DEVICE_NAME "ESP32"
#define TEST_MANUFACTURER_DATA_LEN 17
#define GATTS_DEMO_CHAR_VAL_LEN_MAX 0x40
#define PREPARE_BUF_MAX_SIZE 1024
static esp_gatt_char_prop_t a_property = 0;
static uint8_t adv_config_done = 0;
#define adv_config_flag (1 << 0)
#define scan_rsp_config_flag (1 << 1)
static uint8_t adv_service_uuid128[32] = {
    0xfb,
    0x34,
    0x9b,
    0x5f,
    0x80,
    0x00,
    0x00,
    0x80,
    0x00,
    0x10,
    0x00,
    0x00,
    0xEE,
    0x00,
    0x00,
    0x00,
    0xfb,
    0x34,
    0x9b,
    0x5f,
    0x80,
    0x00,
    0x00,
    0x80,
    0x00,
    0x10,
    0x00,
    0x00,
    0xFF,
    0x00,
    0x00,
    0x00,
};
static esp_ble_adv_data_t adv_data = {
    .set_scan_rsp = false,
    .include_name = true,
    .include_txpower = false,
    .min_interval = 0x0006,
    .max_interval = 0x0010,
    .service_uuid_len = sizeof(adv_service_uuid128),
    .p_service_uuid = adv_service_uuid128,
    .flag = (ESP_BLE_ADV_FLAG_GEN_DISC | ESP_BLE_ADV_FLAG_BREDR_NOT_SPT),
};
static esp_ble_adv_data_t scan_rsp_data = {
    .set_scan_rsp = true,
    .include_name = true,
    .include_txpower = true,
    .service_uuid_len = sizeof(adv_service_uuid128),
    .p_service_uuid = adv_service_uuid128,
    .flag = (ESP_BLE_ADV_FLAG_GEN_DISC | ESP_BLE_ADV_FLAG_BREDR_NOT_SPT),
};
static esp_ble_adv_params_t adv_params = {
    .adv_int_min = 0x20,
    .adv_int_max = 0x40,
    .adv_type = ADV_TYPE_IND,
    .own_addr_type = BLE_ADDR_TYPE_PUBLIC,
    .channel_map = ADV_CHNL_ALL,
    .adv_filter_policy = ADV_FILTER_ALLOW_SCAN_ANY_CON_ANY,
};
#define PROFILE_NUM 1
#define PROFILE_A_APP_ID 0
struct gatts_profile_inst
{
    esp_gatts_cb_t gatts_cb;
    uint16_t gatts_if;
    uint16_t app_id;
    uint16_t conn_id;
    uint16_t service_handle;
    esp_gatt_srvc_id_t service_id;
    uint16_t char_handle;
    esp_bt_uuid_t char_uuid;
    esp_gatt_perm_t perm;
    esp_gatt_char_prop_t property;
    uint16_t descr_handle;
    esp_bt_uuid_t descr_uuid;
};
static struct gatts_profile_inst gl_profile_tab[PROFILE_NUM] = {
    [PROFILE_A_APP_ID] = {
        .gatts_cb = gatts_profile_event_handler,
        .gatts_if = ESP_GATT_IF_NONE,
    },
};
typedef struct
{
    uint8_t *prepare_buf;
    int prepare_len;
} prepare_type_env_t;
static prepare_type_env_t a_prepare_write_env;
void example_write_event_env(esp_gatt_if_t gatts_if, prepare_type_env_t *prepare_write_env, esp_ble_gatts_cb_param_t *param);
static void gap_event_handler(esp_gap_ble_cb_event_t event, esp_ble_gap_cb_param_t *param)
{
    switch (event)
    {
    case ESP_GAP_BLE_ADV_DATA_SET_COMPLETE_EVT:
        adv_config_done &= (~adv_config_flag);
        if (adv_config_done == 0)
        {
            esp_ble_gap_start_advertising(&adv_params);
        }
        break;
    case ESP_GAP_BLE_SCAN_RSP_DATA_SET_COMPLETE_EVT:
        adv_config_done &= (~scan_rsp_config_flag);
        if (adv_config_done == 0)
        {
            esp_ble_gap_start_advertising(&adv_params);
        }
        break;
    case ESP_GAP_BLE_ADV_START_COMPLETE_EVT:
        if (param->adv_start_cmpl.status != ESP_BT_STATUS_SUCCESS)
        {
            ESP_LOGE(GATTS_TAG, "Advertising start failed\n");
        }
        break;
    case ESP_GAP_BLE_ADV_STOP_COMPLETE_EVT:
        if (param->adv_stop_cmpl.status != ESP_BT_STATUS_SUCCESS)
        {
            ESP_LOGE(GATTS_TAG, "Advertising stop failed\n");
        }
        else
        {
            ESP_LOGI(GATTS_TAG, "Stop adv successfully\n");
        }
        break;
    case ESP_GAP_BLE_UPDATE_CONN_PARAMS_EVT:
        ESP_LOGI(GATTS_TAG, "update connection params status = %d, min_int = %d, max_int = %d,conn_int = %d,latency = %d, timeout = %d",
                 param->update_conn_params.status,
                 param->update_conn_params.min_int,
                 param->update_conn_params.max_int,
                 param->update_conn_params.conn_int,
                 param->update_conn_params.latency,
                 param->update_conn_params.timeout);
        break;
    default:
        break;
    }
}
void example_write_event_env(esp_gatt_if_t gatts_if, prepare_type_env_t *prepare_write_env, esp_ble_gatts_cb_param_t *param)
{
    esp_gatt_status_t status = ESP_GATT_OK;

    if (param->write.need_rsp)
    {
        if (param->write.is_prep)
        {
            if (prepare_write_env->prepare_buf == NULL)
            {
                prepare_write_env->prepare_buf = (uint8_t *)malloc(PREPARE_BUF_MAX_SIZE * sizeof(uint8_t));
                prepare_write_env->prepare_len = 0;

                if (prepare_write_env->prepare_buf == NULL)
                {
                    status = ESP_GATT_NO_RESOURCES;
                }
            }

            if (status == ESP_GATT_OK)
            {
                if (param->write.offset <= PREPARE_BUF_MAX_SIZE && (param->write.offset + param->write.len) <= PREPARE_BUF_MAX_SIZE)
                {
                    memcpy(prepare_write_env->prepare_buf + param->write.offset, param->write.value, param->write.len);
                    prepare_write_env->prepare_len += param->write.len;
                }
                else
                {
                    status = (param->write.offset > PREPARE_BUF_MAX_SIZE) ? ESP_GATT_INVALID_OFFSET : ESP_GATT_INVALID_ATTR_LEN;
                }
            }
        }

        esp_gatt_rsp_t gatt_rsp = {
            .attr_value.len = param->write.len,
            .attr_value.handle = param->write.handle,
            .attr_value.offset = param->write.offset,
            .attr_value.auth_req = ESP_GATT_AUTH_REQ_NONE};

        memcpy(gatt_rsp.attr_value.value, param->write.value, param->write.len);
        esp_ble_gatts_send_response(gatts_if, param->write.conn_id, param->write.trans_id, status, &gatt_rsp);
    }
}
static void gatts_profile_event_handler(esp_gatts_cb_event_t event, esp_gatt_if_t gatts_if, esp_ble_gatts_cb_param_t *param)
{
    switch (event)
    {
    case ESP_GATTS_REG_EVT:
        ESP_LOGI(GATTS_TAG, "REGISTER_APP_EVT, status %d, app_id %d\n", param->reg.status, param->reg.app_id);
        gl_profile_tab[PROFILE_A_APP_ID].service_id.is_primary = true;
        gl_profile_tab[PROFILE_A_APP_ID].service_id.id.inst_id = 0x00;
        gl_profile_tab[PROFILE_A_APP_ID].service_id.id.uuid.len = ESP_UUID_LEN_16;
        gl_profile_tab[PROFILE_A_APP_ID].service_id.id.uuid.uuid.uuid16 = GATTS_SERVICE_UUID;
        esp_err_t set_dev_name_ret = esp_ble_gap_set_device_name(TEST_DEVICE_NAME);
        if (set_dev_name_ret)
        {
            ESP_LOGE(GATTS_TAG, "set device name failed, error code = %x", set_dev_name_ret);
        }

        esp_err_t ret = esp_ble_gap_config_adv_data(&adv_data);
        if (ret)
        {
            ESP_LOGE(GATTS_TAG, "config adv data failed, error code = %x", ret);
        }
        adv_config_done |= adv_config_flag;
        ret = esp_ble_gap_config_adv_data(&scan_rsp_data);
        if (ret)
        {
            ESP_LOGE(GATTS_TAG, "config scan response data failed, error code = %x", ret);
        }
        adv_config_done |= scan_rsp_config_flag;
        esp_ble_gatts_create_service(gatts_if, &gl_profile_tab[PROFILE_A_APP_ID].service_id, GATTS_NUM_HANDLE);
        break;
    case ESP_GATTS_WRITE_EVT:
    {
        ESP_LOGI(GATTS_TAG, "GATT_WRITE_EVT, conn_id %d, trans_id %" PRIu32 ", handle %d", param->write.conn_id, param->write.trans_id, param->write.handle);
        if (!param->write.is_prep)
        {
            ESP_LOGI(GATTS_TAG, "GATT_WRITE_EVT, value len %d, value :", param->write.len);
            esp_log_buffer_hex(GATTS_TAG, param->write.value, param->write.len);
            // printf("%.*s\n", param->write.len, (char *)param->write.value);

            // The following piece converts the input message from hex to int but currently indicates the ascii.
            int value = 0;
            for (int i = 0; i < param->write.len; i++)
            {
                value = (value << 8) | param->write.value[i];
            }

            switch (value)
            {
            case 48:
                led_status = 0;
                break;

            case 49:
                led_status = 1;
                break;

            case 50: // G
                colors[0] = 1;
                colors[1] = 0;
                colors[2] = 0;
                break;

            case 51: // R
                colors[0] = 0;
                colors[1] = 1;
                colors[2] = 0;
                break;

            case 52: // B
                colors[0] = 0;
                colors[1] = 0;
                colors[2] = 1;
                break;
            }
            printf("Led_status : %d ", led_status);
            printf("Red : %d ", colors[0]);
            printf("Blue : %d ", colors[1]);
            printf("Green : %d ", colors[2]);

            ESP_LOGI(GATTS_TAG, "Value of Message %d", value);
            if (gl_profile_tab[PROFILE_A_APP_ID].descr_handle == param->write.handle && param->write.len == 2)
            {
                uint16_t descr_value = param->write.value[1] << 8 | param->write.value[0];
                if (descr_value == 0x0001)
                {
                    if (a_property & ESP_GATT_CHAR_PROP_BIT_NOTIFY)
                    {
                        ESP_LOGI(GATTS_TAG, "notify enable");
                        uint8_t notify_data[15];
                        for (int i = 0; i < sizeof(notify_data); ++i)
                        {
                            notify_data[i] = i % 0xff;
                        }
                        esp_ble_gatts_send_indicate(gatts_if, param->write.conn_id, gl_profile_tab[PROFILE_A_APP_ID].char_handle,
                                                    sizeof(notify_data), notify_data, false);
                    }
                }
                else if (descr_value == 0x0002)
                {
                    if (a_property & ESP_GATT_CHAR_PROP_BIT_INDICATE)
                    {
                        ESP_LOGI(GATTS_TAG, "indicate enable");
                        uint8_t indicate_data[15];
                        for (int i = 0; i < sizeof(indicate_data); ++i)
                        {
                            indicate_data[i] = i % 0xff;
                        }
                        esp_ble_gatts_send_indicate(gatts_if, param->write.conn_id, gl_profile_tab[PROFILE_A_APP_ID].char_handle,
                                                    sizeof(indicate_data), indicate_data, true);
                    }
                }
                else if (descr_value == 0x0000)
                {
                    ESP_LOGI(GATTS_TAG, "notify/indicate disable ");
                }
                else
                {
                    ESP_LOGE(GATTS_TAG, "unknown descr value");
                    esp_log_buffer_hex(GATTS_TAG, param->write.value, param->write.len);
                }
            }
        }
        example_write_event_env(gatts_if, &a_prepare_write_env, param);
        break;
    }
    case ESP_GATTS_CREATE_EVT:
        ESP_LOGI(GATTS_TAG, "CREATE_SERVICE_EVT, status %d,  service_handle %d\n", param->create.status, param->create.service_handle);
        gl_profile_tab[PROFILE_A_APP_ID].service_handle = param->create.service_handle;
        gl_profile_tab[PROFILE_A_APP_ID].char_uuid.len = ESP_UUID_LEN_16;
        gl_profile_tab[PROFILE_A_APP_ID].char_uuid.uuid.uuid16 = GATTS_CHAR_UUID;

        esp_ble_gatts_start_service(gl_profile_tab[PROFILE_A_APP_ID].service_handle);

        uint16_t char_property = ESP_GATT_CHAR_PROP_BIT_READ | ESP_GATT_CHAR_PROP_BIT_WRITE;
        esp_err_t add_char_ret = esp_ble_gatts_add_char(gl_profile_tab[PROFILE_A_APP_ID].service_handle,
                                                        &gl_profile_tab[PROFILE_A_APP_ID].char_uuid,
                                                        ESP_GATT_PERM_READ | ESP_GATT_PERM_WRITE,
                                                        char_property, NULL, NULL);
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
void app_main(void)
{
    ESP_LOGI(TAG, "Create RMT TX channel");

    rmt_tx_channel_config_t tx_chan_config = {
        .clk_src = RMT_CLK_SRC_DEFAULT, // select source clock
        .gpio_num = RMT_LED_STRIP_GPIO_NUM,
        .mem_block_symbols = 64, // increase the block size can make the LED less flickering
        .resolution_hz = RMT_LED_STRIP_RESOLUTION_HZ,
        .trans_queue_depth = 4, // set the number of transactions that can be pending in the background
    };
    ESP_ERROR_CHECK(rmt_new_tx_channel(&tx_chan_config, &led_chan));

    ESP_LOGI(TAG, "Install led strip encoder");

    led_strip_encoder_config_t encoder_config = {
        .resolution = RMT_LED_STRIP_RESOLUTION_HZ,
    };
    ESP_ERROR_CHECK(rmt_new_led_strip_encoder(&encoder_config, &led_encoder));

    for (int j = 0; j < LED_QTY; j++)
    {
        led_strip_pixels[j * 3 + 0] = 0; // green
        led_strip_pixels[j * 3 + 1] = 0; // red
        led_strip_pixels[j * 3 + 2] = 0; // blue
    }

    ESP_LOGI(TAG, "Enable RMT TX channel");
    ESP_ERROR_CHECK(rmt_enable(led_chan));

    ESP_LOGI(TAG, "Start LED rainbow chase");

    ESP_ERROR_CHECK(rmt_transmit(led_chan, led_encoder, led_strip_pixels, sizeof(led_strip_pixels), &tx_config));

    xTaskCreatePinnedToCore(ble_task, "ble_task", 4096, NULL, 5, NULL, 0);
    xTaskCreatePinnedToCore(LightTask, "LED", 4096, NULL, 10, NULL, 1);

    // zero-initialize the config structure.
    gpio_config_t io_conf = {};
    // disable interrupt
    io_conf.intr_type = GPIO_INTR_DISABLE;
    // set as output mode
    io_conf.mode = GPIO_MODE_OUTPUT;
    // bit mask of the pins that you want to set, GPIO18/19
    io_conf.pin_bit_mask = GPIO_OUTPUT_PIN_SEL;
    // disable pull-down mode
    io_conf.pull_down_en = 0;
    // disable pull-up mode
    io_conf.pull_up_en = 0;
    // configure GPIO with the given settings
    ESP_ERROR_CHECK(gpio_config(&io_conf));

    gpio_set_level(GPIO_OUTPUT_19, 0); // sel2 = A1
    gpio_set_level(GPIO_OUTPUT_18, 0); // sel1 = A0

    // bit mask of the pins, use GPIO27 here
    io_conf.pin_bit_mask = GPIO_INPUT_PIN_SEL;
    // set as input mode
    io_conf.mode = GPIO_MODE_INPUT;
    // disable pull-down mode
    io_conf.pull_down_en = 0;
    // enable pull-up mode
    io_conf.pull_up_en = 1;
    // interrupt of rising edge
    io_conf.intr_type = GPIO_INTR_POSEDGE;

    ESP_ERROR_CHECK(gpio_config(&io_conf));

    // install gpio isr service
    gpio_install_isr_service(ESP_INTR_FLAG_DEFAULT);
    // hook isr handler for specific gpio pin
    gpio_isr_handler_add(GPIO_INPUT_27, gpio_isr_handler, (void *)GPIO_INPUT_27);

    esp_err_t ret;
    uint32_t ret_num = 0;

    memset(result, 0xcc, READ_LEN);

    s_task_handle = xTaskGetCurrentTaskHandle();

    adc_continuous_handle_t handle = NULL;
    continuous_adc_init(channel, sizeof(channel) / sizeof(adc_channel_t), &handle);

    adc_continuous_evt_cbs_t cbs = {
        .on_conv_done = s_conv_done_cb,
    };
    ESP_ERROR_CHECK(adc_continuous_register_event_callbacks(handle, &cbs, NULL));
    ESP_ERROR_CHECK(adc_continuous_start(handle));

    while (1)
    {
        /**
         * This is to show you the way to use the ADC continuous mode driver event callback.
         * This `ulTaskNotifyTake` will block when the data processing in the task is fast.
         * However in this example, the data processing (print) is slow, so you barely block here.
         *
         * Without using this event callback (to notify this task), you can still just call
         * `adc_continuous_read()` here in a loop, with/without a certain block timeout.
         */
        ulTaskNotifyTake(pdTRUE, portMAX_DELAY);

        while (1)
        {
            ret = adc_continuous_read(handle, result, READ_LEN, &ret_num, 1);
            if (ret == ESP_OK)
            {
                // ESP_LOGI("TASK", "ret is %x, ret_num is %" PRIu32, ret, ret_num);
                // for (int i = 0; i < ret_num; i += SOC_ADC_DIGI_RESULT_BYTES)
                // {
                //     adc_digi_output_data_t *p = (void *)&result[i];
                //     if (check_valid_data(p))
                //     {
                //         ESP_LOGI(TAG, "Unit: %d, Channel: %d, Value: %u", 1, p->type1.channel, result[i]);
                //     }
                //     else
                //     {
                //         ESP_LOGI(TAG, "Invalid data");
                //     }
                // }
                /**
                 * Because printing is slow, so every time you call `ulTaskNotifyTake`, it will immediately return.
                 * To avoid a task watchdog timeout, add a delay here. When you replace the way you process the data,
                 * usually you don't need this delay (as this task will block for a while).
                 */

                // vTaskDelay(1);
            }
            else if (ret == ESP_ERR_TIMEOUT)
            {
                // We try to read `READ_LEN` until API returns timeout, which means there's no available data
                break;
            }
        }
    }

    ESP_ERROR_CHECK(adc_continuous_stop(handle));
    ESP_ERROR_CHECK(adc_continuous_deinit(handle));
}

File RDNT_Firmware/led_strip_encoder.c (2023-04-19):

/*
 * SPDX-FileCopyrightText: 2021-2022 Espressif Systems (Shanghai) CO LTD
 *
 * SPDX-License-Identifier: Apache-2.0
 */

#include "esp_check.h"
#include "led_strip_encoder.h"

static const char *TAG = "led_encoder";

typedef struct
{
    rmt_encoder_t base;
    rmt_encoder_t *bytes_encoder;
    rmt_encoder_t *copy_encoder;
    int state;
    rmt_symbol_word_t reset_code;
} rmt_led_strip_encoder_t;

static size_t rmt_encode_led_strip(rmt_encoder_t *encoder, rmt_channel_handle_t channel, const void *primary_data, size_t data_size, rmt_encode_state_t *ret_state)
{
    rmt_led_strip_encoder_t *led_encoder = __containerof(encoder, rmt_led_strip_encoder_t, base);
    rmt_encoder_handle_t bytes_encoder = led_encoder->bytes_encoder;
    rmt_encoder_handle_t copy_encoder = led_encoder->copy_encoder;
    rmt_encode_state_t session_state = 0;
    rmt_encode_state_t state = 0;
    size_t encoded_symbols = 0;
    switch (led_encoder->state)
    {
    case 0: // send RGB data
        encoded_symbols += bytes_encoder->encode(bytes_encoder, channel, primary_data, data_size, &session_state);
        if (session_state & RMT_ENCODING_COMPLETE)
        {
            led_encoder->state = 1; // switch to next state when current encoding session finished
        }
        if (session_state & RMT_ENCODING_MEM_FULL)
        {
            state |= RMT_ENCODING_MEM_FULL;
            goto out; // yield if there's no free space for encoding artifacts
        }
    // fall-through
    case 1: // send reset code
        encoded_symbols += copy_encoder->encode(copy_encoder, channel, &led_encoder->reset_code,
                                                sizeof(led_encoder->reset_code), &session_state);
        if (session_state & RMT_ENCODING_COMPLETE)
        {
            led_encoder->state = 0; // back to the initial encoding session
            state |= RMT_ENCODING_COMPLETE;
        }
        if (session_state & RMT_ENCODING_MEM_FULL)
        {
            state |= RMT_ENCODING_MEM_FULL;
            goto out; // yield if there's no free space for encoding artifacts
        }
    }
out:
    *ret_state = state;
    return encoded_symbols;
}

static esp_err_t rmt_del_led_strip_encoder(rmt_encoder_t *encoder)
{
    rmt_led_strip_encoder_t *led_encoder = __containerof(encoder, rmt_led_strip_encoder_t, base);
    rmt_del_encoder(led_encoder->bytes_encoder);
    rmt_del_encoder(led_encoder->copy_encoder);
    free(led_encoder);
    return ESP_OK;
}

static esp_err_t rmt_led_strip_encoder_reset(rmt_encoder_t *encoder)
{
    rmt_led_strip_encoder_t *led_encoder = __containerof(encoder, rmt_led_strip_encoder_t, base);
    rmt_encoder_reset(led_encoder->bytes_encoder);
    rmt_encoder_reset(led_encoder->copy_encoder);
    led_encoder->state = 0;
    return ESP_OK;
}

esp_err_t rmt_new_led_strip_encoder(const led_strip_encoder_config_t *config, rmt_encoder_handle_t *ret_encoder)
{
    esp_err_t ret = ESP_OK;
    rmt_led_strip_encoder_t *led_encoder = NULL;
    ESP_GOTO_ON_FALSE(config && ret_encoder, ESP_ERR_INVALID_ARG, err, TAG, "invalid argument");
    led_encoder = calloc(1, sizeof(rmt_led_strip_encoder_t));
    ESP_GOTO_ON_FALSE(led_encoder, ESP_ERR_NO_MEM, err, TAG, "no mem for led strip encoder");
    led_encoder->base.encode = rmt_encode_led_strip;
    led_encoder->base.del = rmt_del_led_strip_encoder;
    led_encoder->base.reset = rmt_led_strip_encoder_reset;
    // different led strip might have its own timing requirements, following parameter is for WS2812
    rmt_bytes_encoder_config_t bytes_encoder_config = {
        .bit0 = {
            .level0 = 1,
            .duration0 = 0.3 * config->resolution / 1000000, // T0H=0.3us
            .level1 = 0,
            .duration1 = 0.9 * config->resolution / 1000000, // T0L=0.9us
        },
        .bit1 = {
            .level0 = 1,
            .duration0 = 0.9 * config->resolution / 1000000, // T1H=0.9us
            .level1 = 0,
            .duration1 = 0.3 * config->resolution / 1000000, // T1L=0.3us
        },
        .flags.msb_first = 1 // WS2812 transfer bit order: G7...G0R7...R0B7...B0
    };
    ESP_GOTO_ON_ERROR(rmt_new_bytes_encoder(&bytes_encoder_config, &led_encoder->bytes_encoder), err, TAG, "create bytes encoder failed");
    rmt_copy_encoder_config_t copy_encoder_config = {};
    ESP_GOTO_ON_ERROR(rmt_new_copy_encoder(&copy_encoder_config, &led_encoder->copy_encoder), err, TAG, "create copy encoder failed");

    uint32_t reset_ticks = config->resolution / 1000000 * 50 / 2; // reset code duration defaults to 50us
    led_encoder->reset_code = (rmt_symbol_word_t){
        .level0 = 0,
        .duration0 = reset_ticks,
        .level1 = 0,
        .duration1 = reset_ticks,
    };
    *ret_encoder = &led_encoder->base;
    return ESP_OK;
err:
    if (led_encoder)
    {
        if (led_encoder->bytes_encoder)
        {
            rmt_del_encoder(led_encoder->bytes_encoder);
        }
        if (led_encoder->copy_encoder)
        {
            rmt_del_encoder(led_encoder->copy_encoder);
        }
        free(led_encoder);
    }
    return ret;
}

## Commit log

2023-01-28 Made changed to led and progress
2023-02-02 addded kicad project
    [RDNT_PCB.kicad_pcb, RDNT_PCB.kicad_sch]
2023-02-02 Updated schematic to current circuitry
    [RDNT_PCB.kicad_sch]
2023-02-08 added FFT+Gaussian+LED program
2023-02-14 added documents/refs and fixed formatting on my progress reports
    [A7 - Bill of Materials.xlsx]
2023-02-19 added espidf fft adc without LED
2023-02-22 updated references after foot print verification day 1
2023-02-28 added led strip datasheet
2023-03-02 website updated pcb and presentation
    [RDNT_PCB-B_Cu.gbr, RDNT_PCB-B_Mask.gbr, RDNT_PCB-B_Paste.gbr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]
2023-03-02 CAD updated
    [Housing Complete v6.f3z, LED Fixture v4.f3d]
2023-03-13 PCB Updated
    [RDNT_PCB.kicad_pcb, RDNT_PCB.kicad_sch]
2023-03-14 zipped grb drl
    [RDNT_PCB-B_Mask.gbr, RDNT_PCB-B_Silkscreen.gbr, RDNT_PCB-Back.gbr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]
2023-03-21 pushed pcb on website
2023-03-21 Drill Files Uploaded
    [RDNT_PCB.csv]
2023-03-21 updated file struct
    [Housing Complete v6.f3z, LED Fixture v4.f3d]
2023-03-30 got PWM working for black/white control. added file for testing the pcb
2023-04-04 added led driving prototype file
2023-04-05 added a test file for mode switch
2023-04-05 added test file for mode button and caseled
2023-04-06 fixed small bugs on verification files
    [TestMCU_ModeButton.c, TestMCU_ModeCaseLED.c]
2023-04-06 fixed mode button :D
    [TestMCU_ModeButton.c]
2023-04-08 Created a workflow for no interruption
2023-04-14 fixed debouncing on modebutton/case_led
    [TestMCU_ModeCaseLED.c]
2023-04-14 ESP_ITER1
    With ADC , Bluetooth
2023-04-14 better mode switching, changes muxx outputs now as well
2023-04-19 added LED encoder files
2023-04-21 fixed dc voltage scaling for gaussian
    [ESP_ITER3.c]

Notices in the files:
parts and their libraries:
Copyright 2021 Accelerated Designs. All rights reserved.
